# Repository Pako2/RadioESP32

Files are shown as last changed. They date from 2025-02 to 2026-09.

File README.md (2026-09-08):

# RadioESP32
RadioESP32 is a high-performance multimedia platform built on the ESP32 architecture. Originally starting as a dedicated standalone internet radio, the platform has evolved significantly. Starting with version 2.0.0, the project has been completely re-engineered into an advanced multi-boot system that transforms a single hardware device into an Internet Radio player, a local SD card audiobook player, and a high-fidelity Bluetooth loudspeaker – all managed by an independent recovery and deployment application.\
**Note:** Complete project documentation can be found in the [UserGuide_EN.pdf](doc/UserGuide_EN.pdf) file.

### Display and embedded web server preview
For illustration, you can see three photos of the display. You may be surprised to see that some of the text lines are blurred. The explanation is simple. This is scrolling text, because otherwise it wouldn't fit on the display!\
The first picture shows the radio playing, the second shows a file playing from an SD card, and the third shows the clock.
<p float="left">
  Radio player
  SD player 
  Clock
</p>

There's no need to describe the appearance of the web interface. You can learn much more from a few screenshots.
<p float="left">
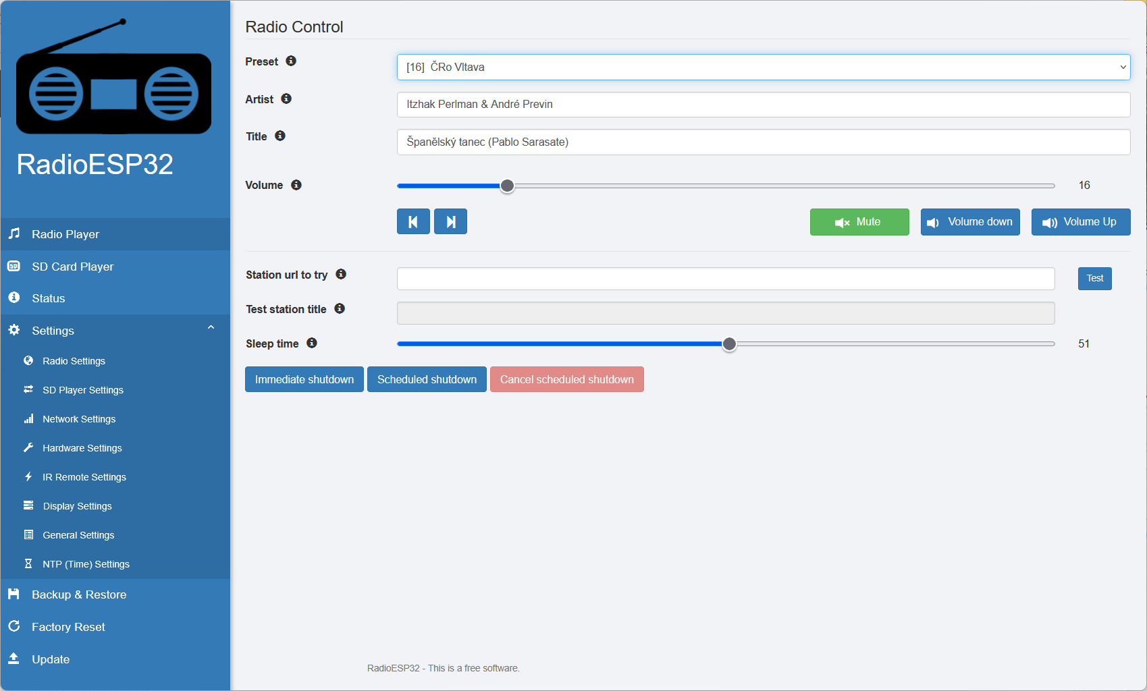
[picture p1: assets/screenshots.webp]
Screenshots
  
</p>

## Project Origin & Acknowledgments
This project would likely never have been created without the popular [ESP32Radio-V2](https://github.com/Edzelf/ESP32Radio-V2) project by [Edzelf](https://github.com/Edzelf). I am deeply grateful to the author for his outstanding work, which served as the original foundation for this software.

While I initially deployed the original project in its unchanged form, several limitations quickly became apparent. My primary motivation for rewriting and expanding the software stemmed from two major issues:

- **Localization:** The original display implementation did not support accented diacritics, which was critical for a proper local user experience.

- **Audiobook Playback:** One of my core requirements was the ability to listen to audiobooks from an SD card. Audiobooks require files to be played in a strict, defined alphabetical order. In the original software, copying files from a PC to an SD card resulted in them being indexed and played in a seemingly random order, making sequential listening highly complicated without constant manual track selection.

Additionally, I preferred a different default behavior. Instead of always resuming the last played station at the previous volume level upon power-up, I prefer the device to initialize to a pre-defined default station and default volume. I also planned to integrate entirely new hardware and software features, such as single-button power toggling and an automated sleep/turn-off timer.

Despite these changes, several core elements from Edzelf's project were retained, which significantly aided my early development. Furthermore, the web interface design, the communication method between the ESP32 and the browser, and the configuration file management system were adopted from the [esp-rfid](https://github.com/esprfid/esp-rfid) project - a highly reliable setup I have successfully utilized across multiple designs.

# Evolution in Version 2.0.0+
During development, I realized that with a purely software-driven approach, the existing hardware design could be utilized as a full-featured Bluetooth loudspeaker. To implement this comfortably, version 2.0.0 underwent a fundamental architectural overhaul.
To streamline production and focus on maximum stability, legacy sub-variants (such as designs without a display or designs storing web server assets directly inside a volatile file system partition) were abandoned. Moving forward, the project is maintained as a single production variant: always equipped with a display and always compiling web server assets directly into the program memory. This specific design is mandatory to support the automated multi-boot Update Manager system.

## Upgrading from Version 1.X.X
If you are upgrading an existing device from a 1.X.X release, your configuration file is fully compatible with the new version. However, due to the fundamental architectural changes mentioned above, a clean installation via cable is required:
- **Backup** your current configuration using the Backup & Restore menu in your existing web interface.
- Perform a **full installation** over a USB cable using the new Flash utility (flash.bat).
- **Restore** your configuration file using the Backup & Restore menu in the new version 2.0.0 interface.

**Note:** 
*Before proceeding with the upgrade, please verify that your hardware meets the new minimum requirements (8MB Flash and PSRAM), as legacy 4MB modules are no longer supported.*

## Legacy Differences: Radio Application vs. Edzelf's ESP32Radio
The following enhancements and modifications apply exclusively to the Internet Radio application (and its web configuration) compared to the original Edzelf implementation:

- **Strict Alphabetical Playback:** Fixed the random indexing issue on SD cards. Files and folders are sorted properly, enabling seamless audiobook listening. However, shuffle mode can be turned on as needed.

- **Diacritics & Extended Character Support:** The display engine was rewritten to support full native character mapping and custom fonts.

- **Predictable Initialization:** The device turns on to a user-defined default station and safe volume level rather than resuming the last state.

- **Single-Button Power Toggle:** Hardware-software integration allows turning the entire device completely on and off using the same single physical button.

- **Integrated Sleep Timer:** Supports a configurable sleep countdown that automatically powers down the hardware.

- **Comfortable Web-Based IR Learning:** Unlike the original project, adding or modifying infrared remote control commands is managed through an incredibly intuitive and automated web interface, allowing the device to capture and assign raw hardware codes on the fly.

# Full-Featured Bluetooth Loudspeaker Application
The Bluetooth Loudspeaker mode (running on OTA\_1) is engineered to deliver a premium commercial-grade user experience, offering deep visual feedback and control options rarely found in DIY audio systems.

## Key features include:
- **Identical Display Dashboard:** The physical display mirrors the rich visual interface of the Radio application, showing a real-time battery status indicator, an active volume bar, and a track progress bar.

- **Dynamic Status Icons:** Features clear visual indicators for Bluetooth connectivity (color-coded blue for active connection, grey for disconnected state) along with dedicated Play/Pause status indicators.

- **Rich Metadata & Auto-Scrolling:** Streams live metadata directly from the connected smartphone. Track titles, artist names, and album details are fully processed and rendered with native diacritic support, automatically triggering a smooth text-scrolling engine if the text length exceeds the screen boundaries.

- **Dual Physical Control Layers:** The loudspeaker can be controlled fully via the mechanical physical rotary encoder or completely hands-free using an Infrared Remote Control (handling Play, Pause, Track Skip, and Volume adjustments).

- **Centralized Configuration:** Because the Bluetooth application completely turns off the Wi-Fi stack to eliminate protocol overhead and interference, it does not host a web server. Instead, all Bluetooth-specific settings (including custom broadcast device naming and the advanced IR remote control command learning) are comfortably configured inside the unified web interface of the Internet Radio application.

# System Architecture & Multi-Boot Partitioning
Due to the strict hardware limitations of the ESP32 chip (specifically the high instability and memory constraints of running Wi-Fi and Bluetooth stacks simultaneously) the system separates core features into completely independent firmware binaries.

The system utilizes a custom partition layout designed for 8MB Flash chips. The minimum required hardware configuration is the ESP32-WROVER-E-N8R4 module. Volatile PSRAM memory is mandatory, as modern versions of the underlying audio libraries will not function without it.

## The memory layout divides the hardware into four distinct primary zones:
| Partition Type | Application Name | Core Functionality | Network State |
| - | - | - | - |
| **Factory** | Update Manager | Recovery, deployment, and binary flashing | Wi-Fi (Station with Internet) |
| **OTA\_0** | Internet Radio | Web-streaming, SD card media player | Wi-Fi (Station / Initial AP Setup) |
| **OTA\_1** | BT Loudspeaker | High-fidelity A2DP audio playback | Completely Disabled (No Wi-Fi) |
| **LittleFS** | Configuration | Shared system settings and profiles | Non-volatile storage |

All three applications share a single, unified configuration file stored in the LittleFS zone. Switching between applications triggers a low-level hardware reset using direct RTC controller registry manipulation, ensuring that the hardware cache and DMA controllers are completely cleared for a pure warm boot.

# Independent Update Manager
Because individual OTA application partitions contain completely different binary structures (Radio vs. Bluetooth), traditional OTA upgrades (where a new version is uploaded to an inactive slot and toggled) are impossible.

The project solves this by deploying a completely independent recovery application in the factory partition. When triggered via the display menu or the radio's web interface, the device reboots into the red-themed Update Manager web server (accessible via the credentials defined in the source code). From this dashboard, users can view live tables comparing current firmware versions against the latest versions available online, perform automated network updates, create full system binary backups, or deploy manual downgrades from local files.
<p float="left">
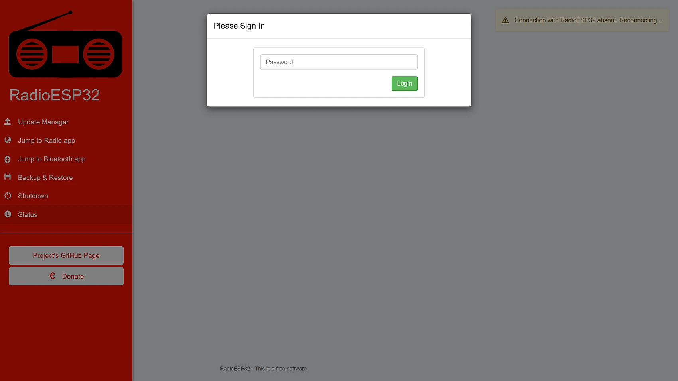
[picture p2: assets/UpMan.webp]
Update Manager
  
</p>

### ⚠️ Important Note regarding Over-the-Air (OTA) Web Upgrades

Due to strict modern browser security standards (CORS policies) implemented by GitHub, web browsers will natively block the JavaScript interface from directly transferring firmware files from GitHub Releases onto your local IP address via the single-click "Update" buttons.

To complete an application upgrade, you have two equally reliable options:

1. **Manual Offline Upload (Recommended & Safest):** 
   Simply click the green **Download** button next to the target application to save the latest `.bin` firmware file directly to your PC. Then, navigate to the **Firmware Upload** panel below, select the correct **Target Application**, click the **Browse...** button to select the downloaded binary from your hard drive, and click **Flash Selected File**.

2. **Direct Web Upgrade (Advanced):**
   If you prefer to upgrade with a single click directly from the web interface using the automated table, you must temporarily enable a CORS-bypass extension in your browser (such as *"Allow CORS: Access-Control-Allow-Origin"* for Chrome/Firefox) before opening the Update Manager dashboard.

The Update Manager features critical system-level fail-safes. If the supply battery drops below a safe operational threshold during an update cycle, an asynchronous JavaScript modal hard-locks the entire web interface, preventing user interactions until safe power parameters are restored, eliminating the risk of accidental firmware bricking.

## Advanced Graphics Engineering
To achieve absolute long-term stability, the graphics pipeline was completely refactored. The Bluetooth application runs an aggressive real-time A2DP data sink. Under standard implementations, multi-core thread collisions frequently occur on the shared SPI display bus when high-priority Bluetooth background tasks on Core 0 interrupt the main application execution loop on Core 1.

The system eliminates these race conditions by removing traditional RTOS mutexes entirely. Instead, all graphic subsystems, status readouts, and display bars (such as the volume bar, battery indicator, progress bars, and scrolling metadata tracks) are completely centralized under a single-task, asynchronous flag-driven pipeline in the display loop. Asynchronous events from Bluetooth callbacks merely flag status variables in RAM, which are safely ingested and drawn by a single dedicated display task.

# Development and Build Flags
The project is developed in VS Code using the PlatformIO IDE paired with the Pioarduino extension. Using environment build flags in `platformio.ini`, the firmware behavior is customized using the following core definitions:

- **DATAWEB=true/false:** Setting this flag to `true` compiles a development variant where web server assets are loaded dynamically from the LittleFS partition, allowing real-time, browser-based source editing via the integrated online [Ace editor](https://ace.c9.io/). Setting this to `false` creates the production variant, compressing and injecting all HTML and JS assets directly into the program memory (PROGMEM) as static variables. This is the mandatory format for deployment binaries.

- **SDCARD:** Compiles full support for the local SD card hardware and alphabetical media player engine.

- **BATTERY:** Enables power monitoring, enabling precise voltage calibration routines and rendering live battery status bars across both the physical display and web dashboards.

- **AUTOSHUTDOWN:** Compiles the control logic for the single-button soft power toggle circuit and the automatic sleep timer.

# Third-Party Libraries & Acknowledgments
This project relies heavily on the open-source community. I would like to express my sincere gratitude to the authors of the following exceptional libraries, whose hard work made this multi-boot platform possible:

- **[ESP32-audioI2S](https://github.com/schreibfaul1/ESP32-audioI2S) by schreibfaul1** – The core engine powering the high-performance internet radio streaming and SD card media playback.

- **[ESP32-A2DP](https://github.com/pschatzmann/ESP32-A2DP) by pschatzmann** – The backbone of the Bluetooth application, providing a reliable and robust real-time A2DP audio sink.

- **[ESPAsyncWebServer](https://github.com/ESP32Async/ESPAsyncWebServer)** – Essential for driving the asynchronous, responsive web interfaces across the platform slots.

- **[ArduinoJson](https://github.com/bblanchon/ArduinoJson) by bblanchon** – Used for fast, memory-efficient parsing of configuration files and the update manager tables.

- **[base64](https://github.com/Densaugeo/base64_arduino) by Densaugeo** – Utilized for secure encoding and handling of system assets and network communication data.

- **[Arduino-IRremote](https://github.com/Arduino-IRremote/Arduino-IRremote)** – Powering the automated infrared remote control receiver and code-learning capabilities.

- **[TFT\_eSPI](https://github.com/Bodmer/TFT_espi) by Bodmer** – The highly optimized graphics driver used to render sprites and smooth scrolling text on the SPI display.

- **[U8g2](https://github.com/olikraus/u8g2) by olikraus** & **[U8g2\_for\_TFT\_eSPI](https://github.com/Bodmer/U8g2_for_TFT_eSPI) by Bodmer** – Providing the comprehensive font support required for native localization, accented diacritics, and system icons.

## PlatformIO Environment & Custom Python Targets
The project utilizes advanced customization features of PlatformIO with the Pioarduino extension to automate the compilation, transformation, and deployment of firmware slots. Since standard environment filters naturally restrict automated serial flashing to the `OTA_0` partition, a dedicated set of specialized automation scripts was engineered to streamline the development workflow:

- **`app_deploy.py` (Binary Archiving):** Executed automatically post-build. It automatically moves and renames compiled images into the structured `/bin/<env>/` directory, preparing them for deployment.

- **`custom_targets.py` (Advanced Workflow Automation):** Exposes core system functions accessible comfortably directly via the *Pioarduino: Project Tasks / \<env\> / Custom* IDE side menu. It processes two critical automated workflows:

  - **Download FS & Create WEBH:** Automates the complete transformation of production web assets. It downloads the live file system image from the hardware using maxgerhardt's downloader utility, extracts the HTML and JS assets from `LittleFS`, and translates them directly into compressed C++ array data variables ready for `PROGMEM` generation.

  - **Upload custom binary:** The primary development flashing mechanism. Instead of pushing blindly to `OTA_0`, this target programmatically parses the local partition configuration table, dynamically locates the precise memory address boundaries for the active target environment, and executes a targeted wired upload directly to the correct slot (`OTA_1` for Bluetooth loudspeaker or `factory` for the Update Manager).

## Production Flash Utilities
For initial provisioning, assembly, and bulk deployment outside the VS Code IDE development sandbox, a dedicated, standalone host script named Flash Utilities is used.
<p float="left">
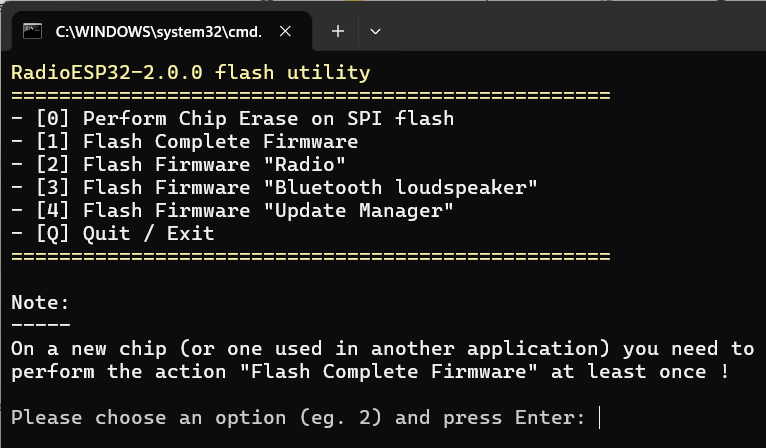
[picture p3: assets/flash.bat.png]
Flash menu
  
</p>
This standalone batch utility operates strictly as a master installation tool tailored for two main deployment scenarios:

1. **Full Environment Initialization:** Performs the first-time wired flashing of a fresh, raw ESP32 chip. It writes the global bootloader configurations, custom multi-boot partition boundaries, the initial `LittleFS` shared configuration image, and all three application binaries concurrently.

2. **Targeted Service Upgrades:** Provides a safe serial bypass tool to manually write or restore a single specific slot over a wired serial connection. This is the mandatory path required for initial installation or forced rewrites of the factory recovery application partition without formatting or impacting user profiles.

On a fresh device provisioning cycle, the system triggers a default fallback standalone Wi-Fi Access Point named **RadioESP32**. Navigating a web browser to `192.168.4.1` loads the initial onboarding setup screen to connect the multi-boot hardware platform to local wireless station configurations.

# Hardware Design & Component Selection
The physical hardware architecture is designed using the free/personal-use tier of Autodesk Eagle, utilizing a dual-stage isolation approach to completely eliminate ground loops, digital switching noise, and interference.

### Wiring diagram
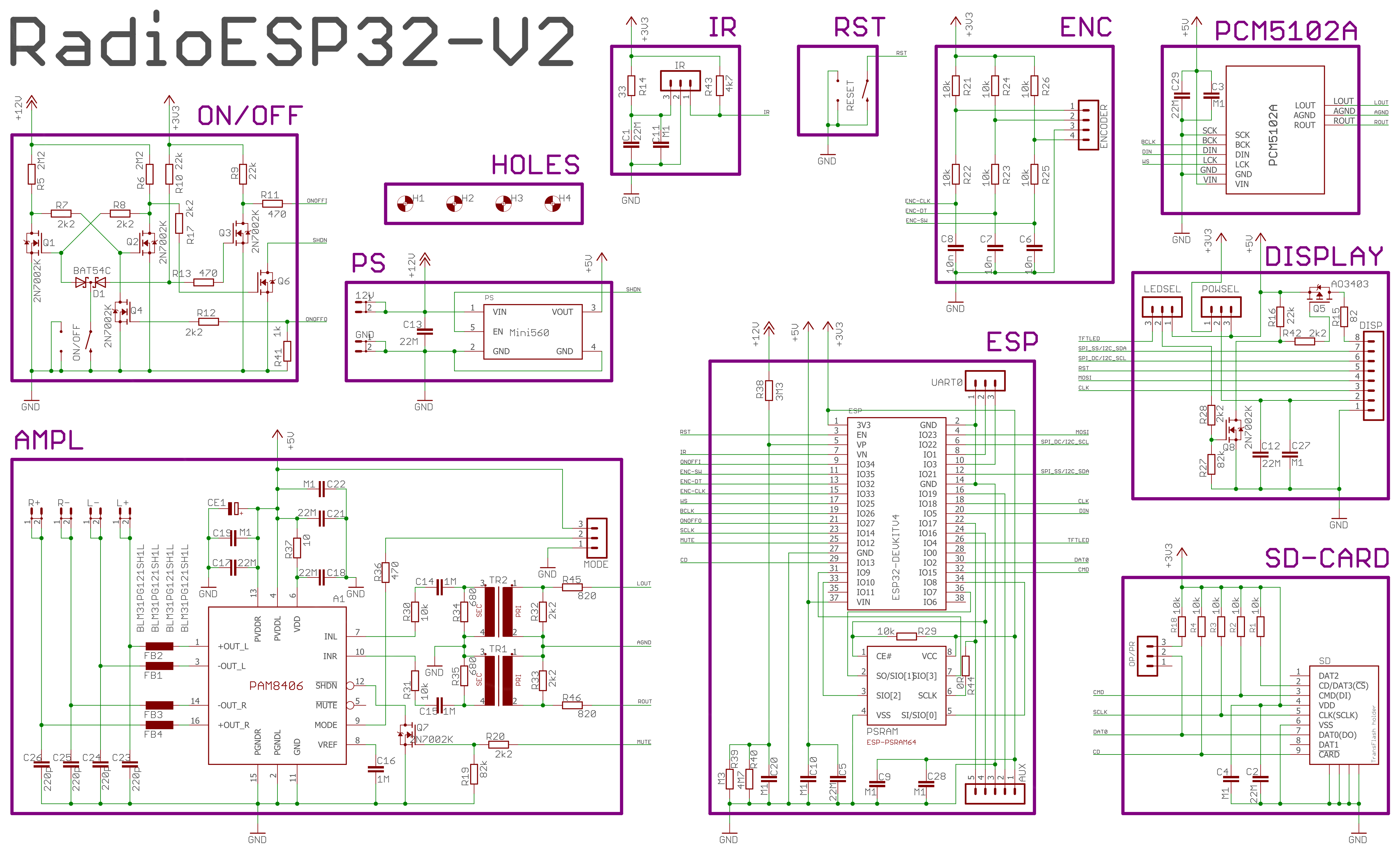
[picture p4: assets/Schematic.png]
Wiring diagram


### Printed circuit board
<p float="left">
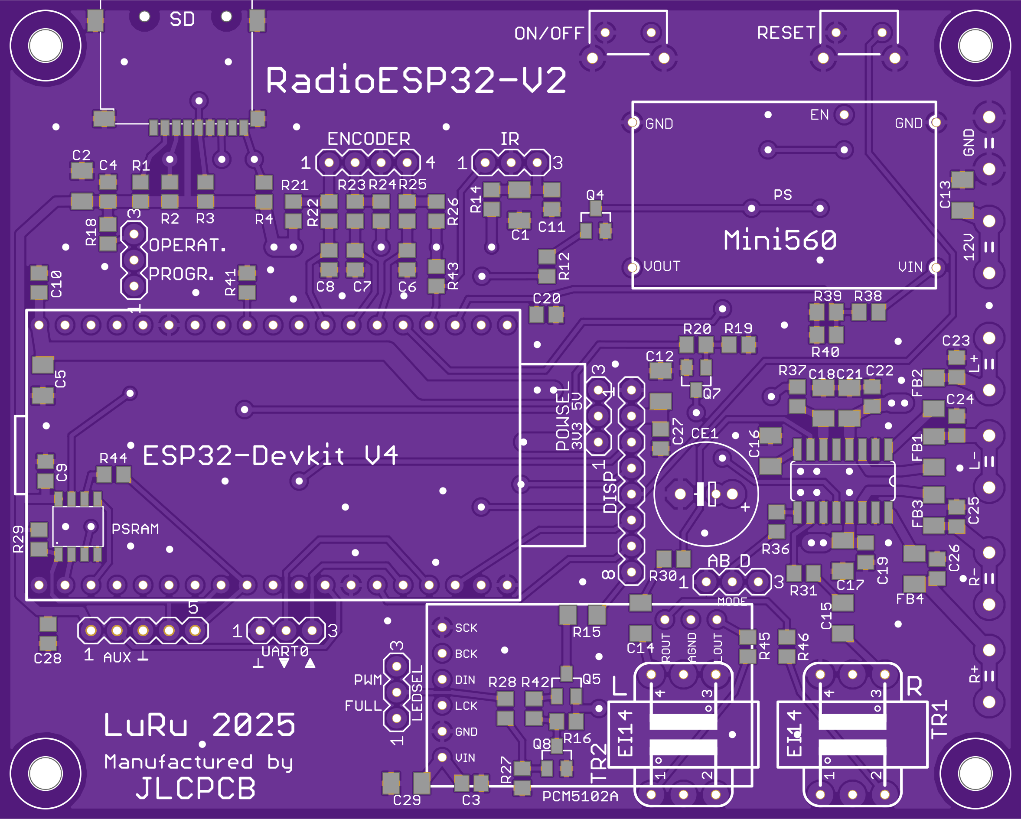
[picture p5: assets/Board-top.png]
PCB top side
  
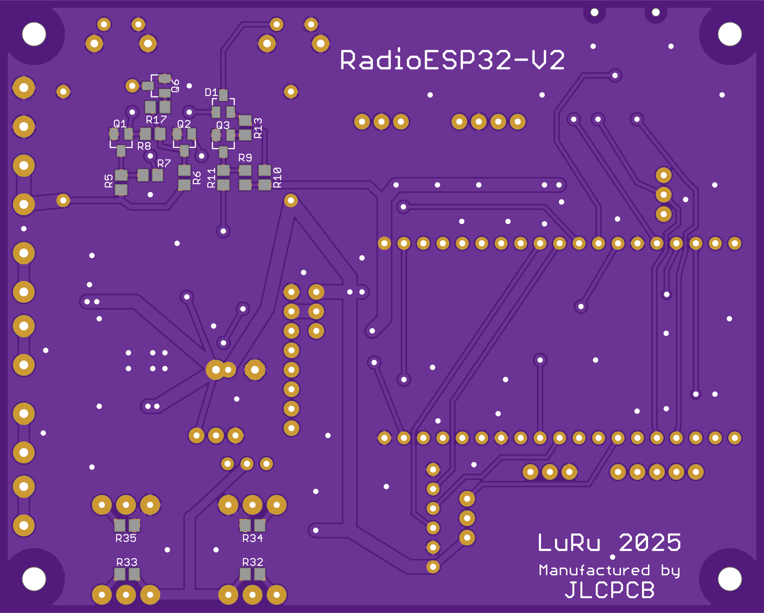
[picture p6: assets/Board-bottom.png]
PCB bottom side
   
</p>

### Choice of components
In the first phase of development, I used the VS1053 module (as a DAC) following Edzelf's example. It worked well, but I found this solution unnecessarily expensive and quite problematic (for example, I once accidentally bought a VS1003 instead and it didn't work well). That's why I completely abandoned this path and switched exclusively to a solution with I2S.
- **Main Processor:** ESP32-WROVER-E module (Silicon Revision 3 or higher, minimum 8MB Flash and 4MB PSRAM).
<p float="left">
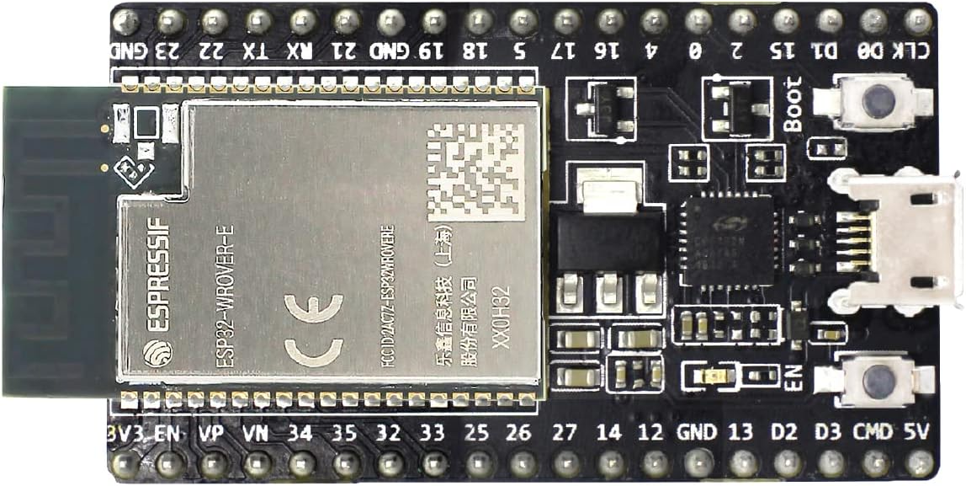
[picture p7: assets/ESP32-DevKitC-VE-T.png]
Development board - top side
  
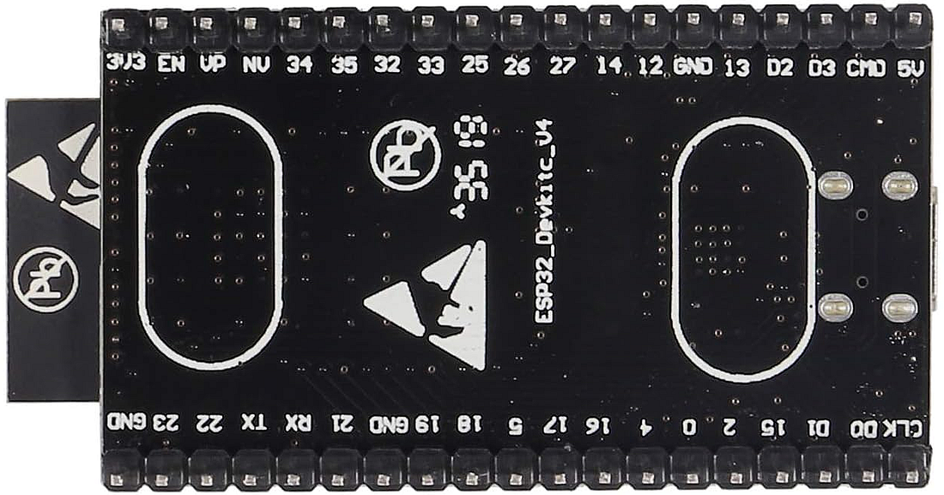
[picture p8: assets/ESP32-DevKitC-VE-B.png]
Development board - bottom side
   
</p>

- **Power Supply:** 12V primary input, optimized to run efficiently from three series-connected 18650 Li-ion cells or a standard wall adapter. A high-efficiency Mini560 step-down module regulates this down to a stable 5V rail. The module's EN (Enable) pin is directly wired into the single-button latching circuit for hard physical power management.
<p float="left">
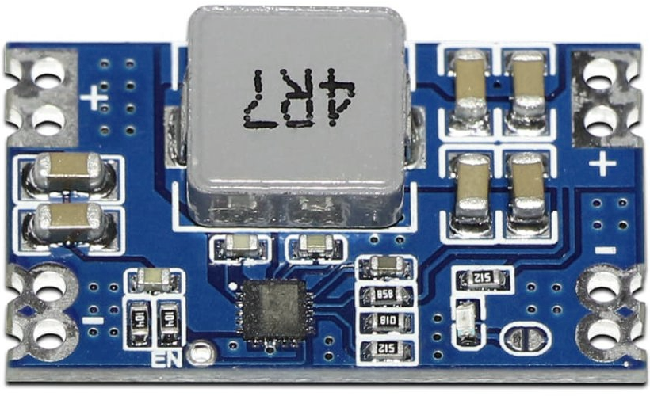
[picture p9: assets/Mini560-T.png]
Step-down converter top side
  
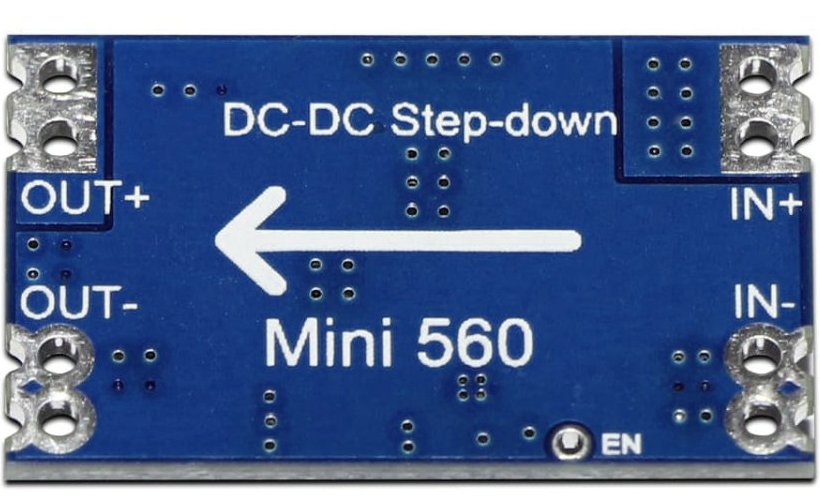
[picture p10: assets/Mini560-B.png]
PStep-down converter bottom side Step-down converter bottom side
   
</p>

- **Audio DAC:** PCM5102A I2S module, selected for its high dynamic range and integrated analog out pin liars, eliminating complex internal chassis cabling.
<p float="left">
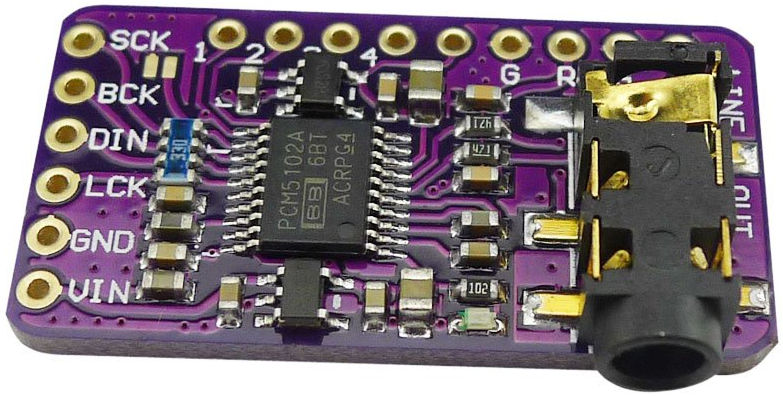
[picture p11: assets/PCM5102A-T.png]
DAC - top side
  
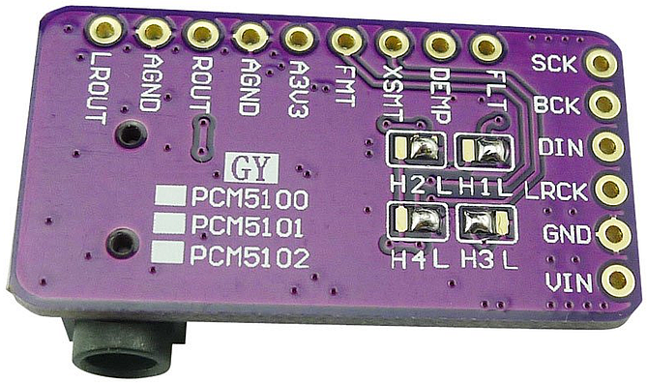
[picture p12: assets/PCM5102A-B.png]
DAC - bottom side
   
</p>

- **Ground Loop Isolation:** Two low-profile 9.1mm audio isolation transformers are placed inline directly between the DAC outputs and the amplifier inputs, successfully blocking digital hum and cross-talk.
<p float="left">
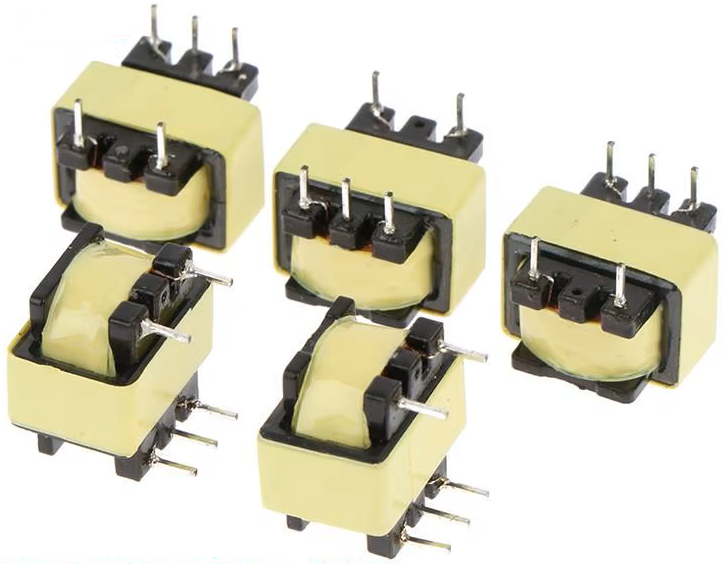
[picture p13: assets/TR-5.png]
Isolation transformers
  
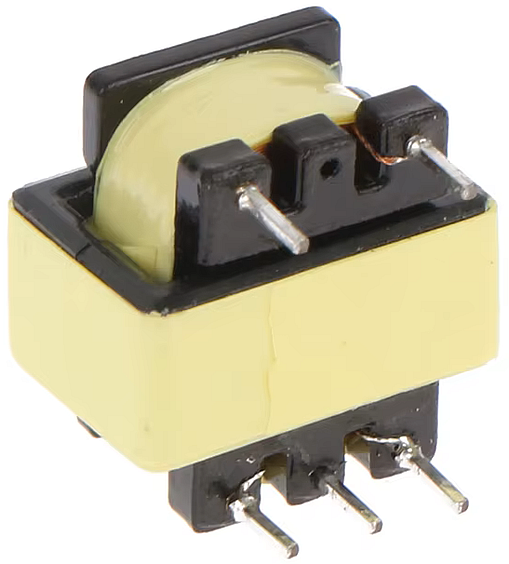
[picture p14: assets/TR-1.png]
Isolation transformer
   
</p>

- **Amplifier Stage:** PAM8406 5V stereo amplifier IC. This specific chip was chosen because it can operate in either Class-D (high efficiency for battery operation) or Class-AB (low RF noise for clean radio reception). The operating mode is manually selected on the PCB via hardware jumpers.
<p align="center" width="100%">
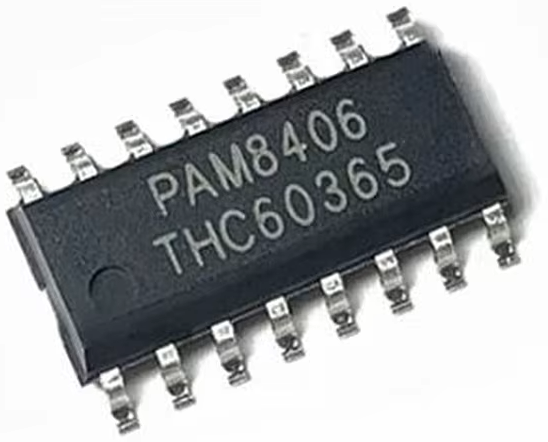
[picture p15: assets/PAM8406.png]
Amplifier amplifier
    
</p>

- **Display Interface:** 1.77-inch SPI TFT panel (160x128 resolution) driven natively by the optimized TFT\_eSPI library.
<p float="left">
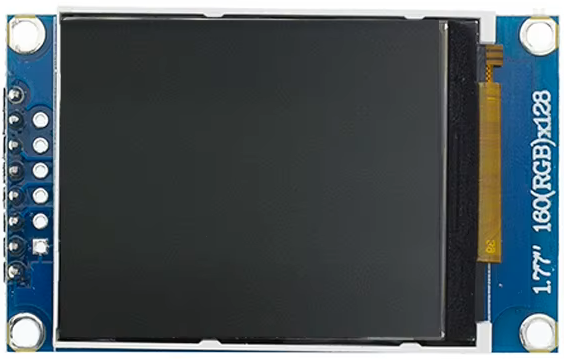
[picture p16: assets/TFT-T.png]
TFT - top side
  
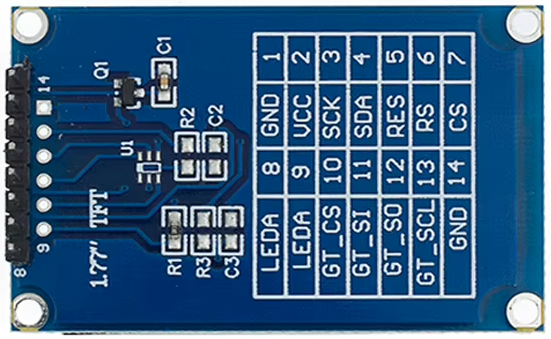
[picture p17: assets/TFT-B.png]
TFT - bottom side
   
</p>

- **User Control:** A robust EC11 mechanical rotary encoder with an integrated push-button handles physical navigation, complemented by a VS1838B infrared receiver supporting automatic remote control code learning.
<p float="left">
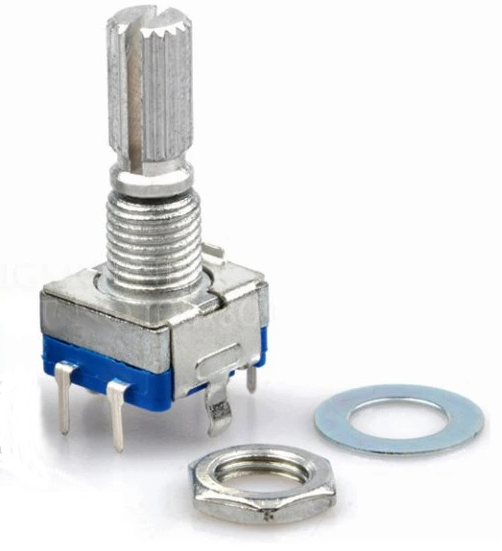
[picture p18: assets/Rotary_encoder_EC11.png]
Rotary encoder
  
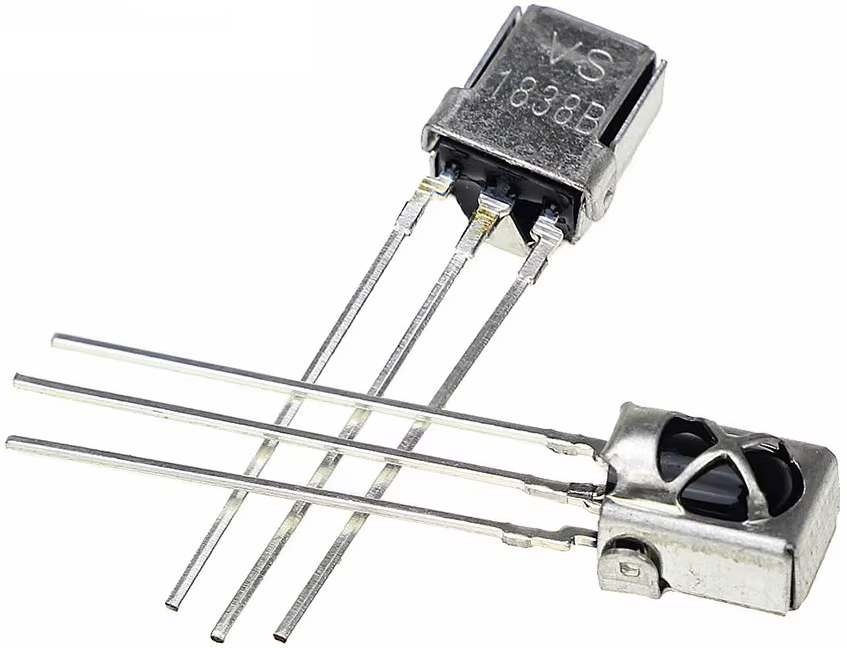
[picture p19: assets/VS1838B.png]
Infrared receiver
   
</p>

- **Chassis Connections:** Traditional screw terminals were replaced with high-reliability 4.8mm male Faston terminals soldered directly to the PCB for all primary power inputs and speaker outputs, ensuring vibrating-proof connections inside the speaker enclosure.
<p float="left">
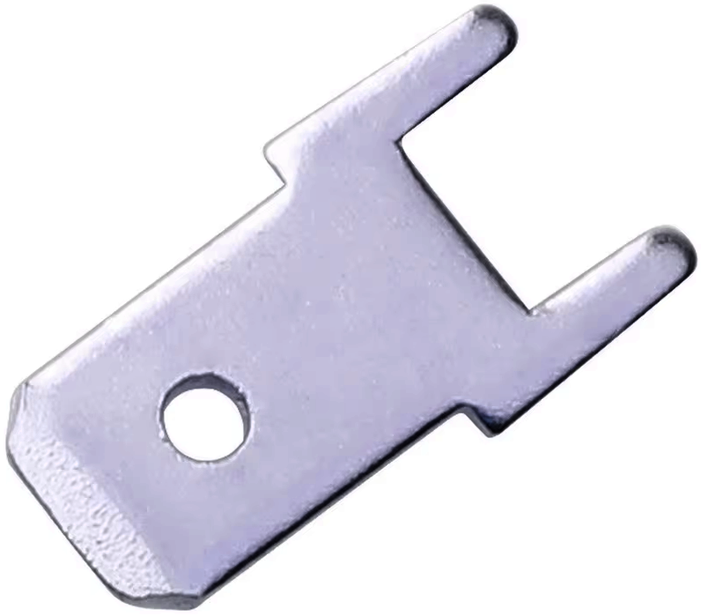
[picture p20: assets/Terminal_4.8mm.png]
Faston connector
   
</p>

## Assembled board
Finally, you can see a few pictures of the printed circuit board completely assembled and including the installed subboards (ESP32 development kit and DAC). I also added one photo of the finished radio (powered by three 18650 Li-ion cells).

PCB 1
PCB 2
PCB 3
PCB 4
PCB 5
PCB 6
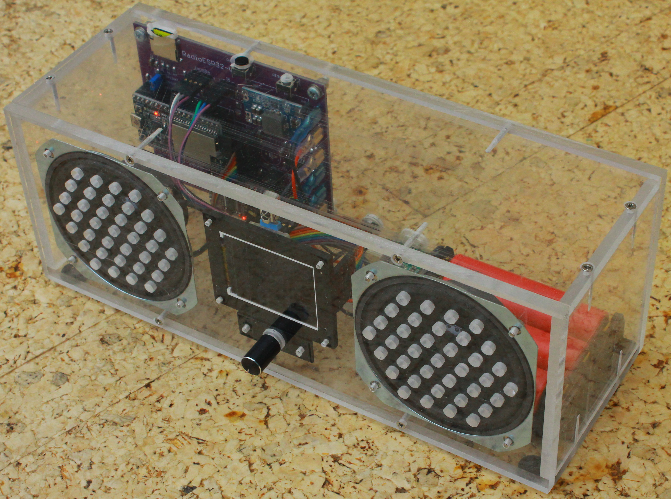
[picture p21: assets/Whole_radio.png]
RADIO


### License
The code parts written by the author of the **RadioESP32** project are licensed under [GPL-3.0](LICENSE), 3rd party libraries that are used by this project are licensed under different license schemes, please check them out as well.

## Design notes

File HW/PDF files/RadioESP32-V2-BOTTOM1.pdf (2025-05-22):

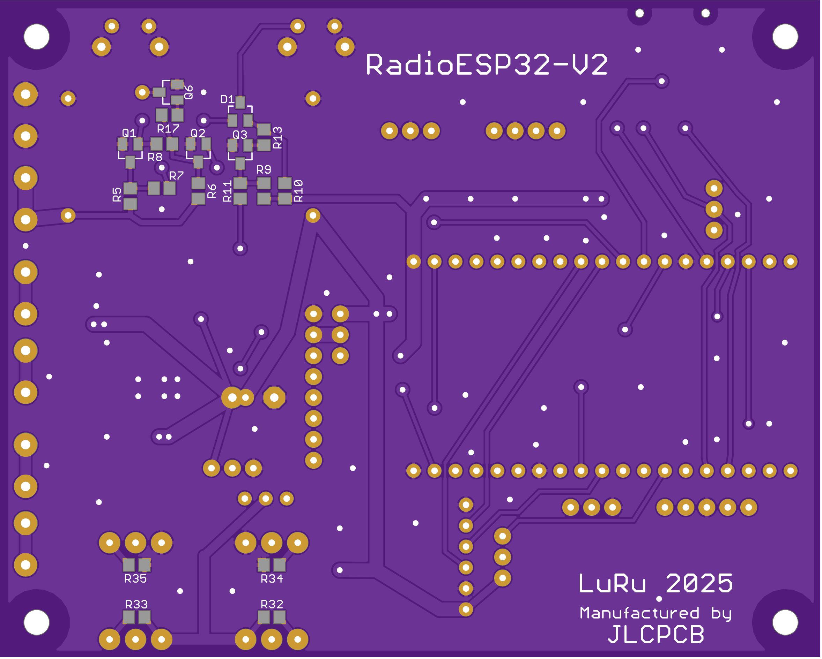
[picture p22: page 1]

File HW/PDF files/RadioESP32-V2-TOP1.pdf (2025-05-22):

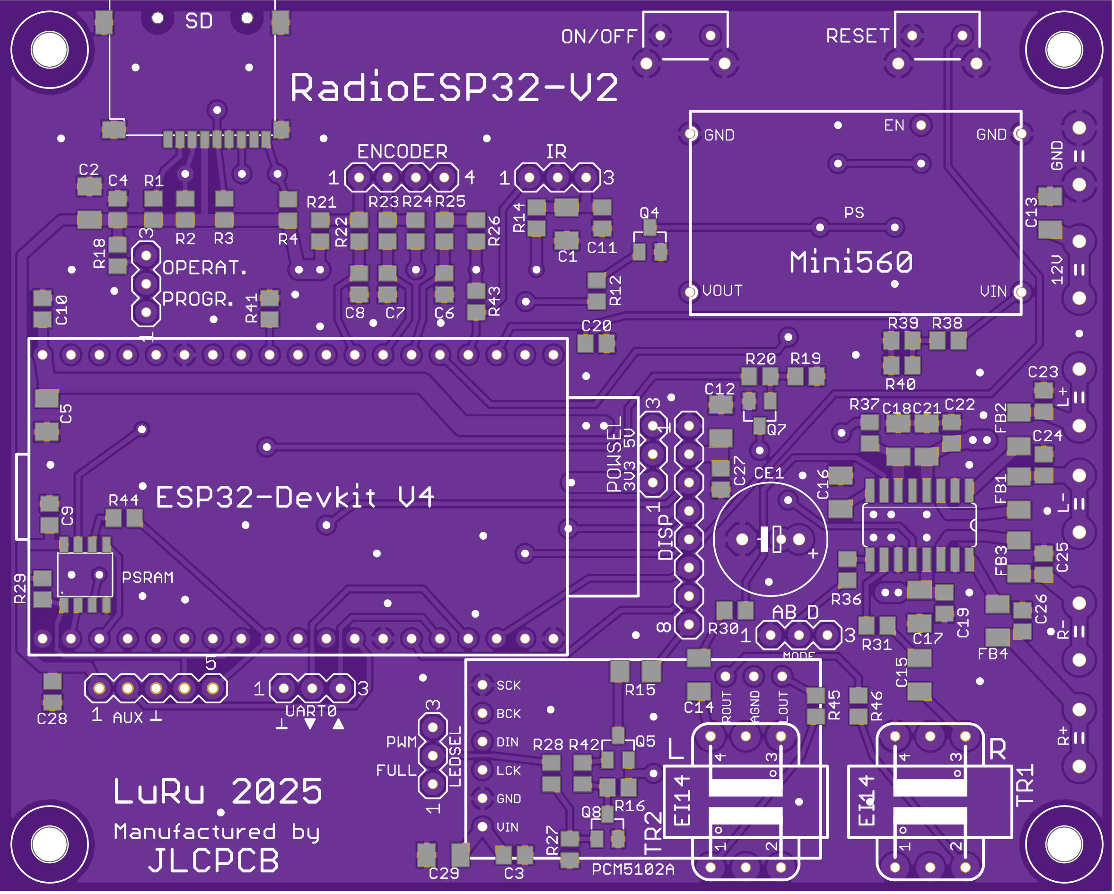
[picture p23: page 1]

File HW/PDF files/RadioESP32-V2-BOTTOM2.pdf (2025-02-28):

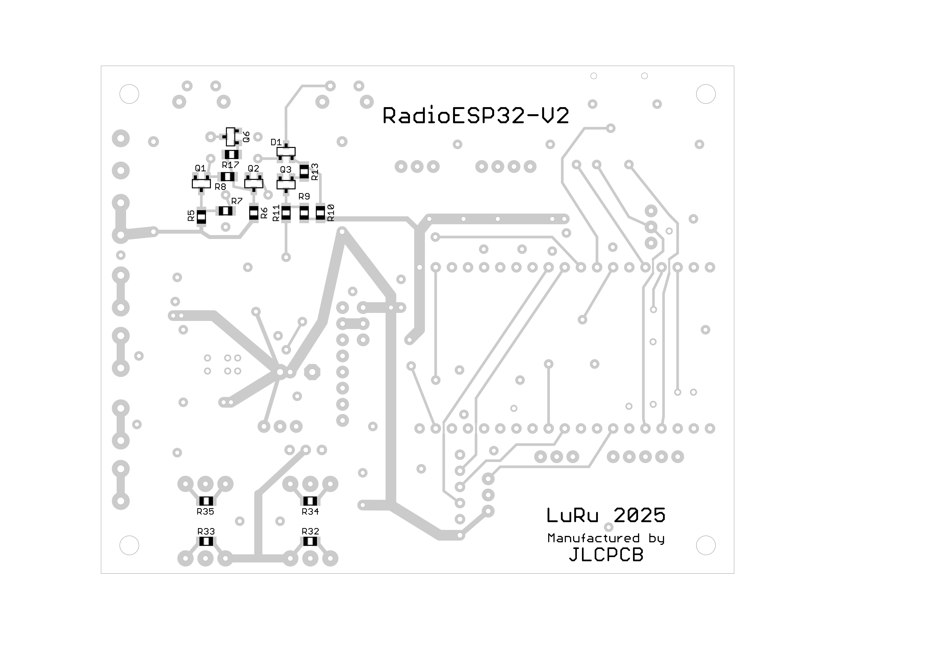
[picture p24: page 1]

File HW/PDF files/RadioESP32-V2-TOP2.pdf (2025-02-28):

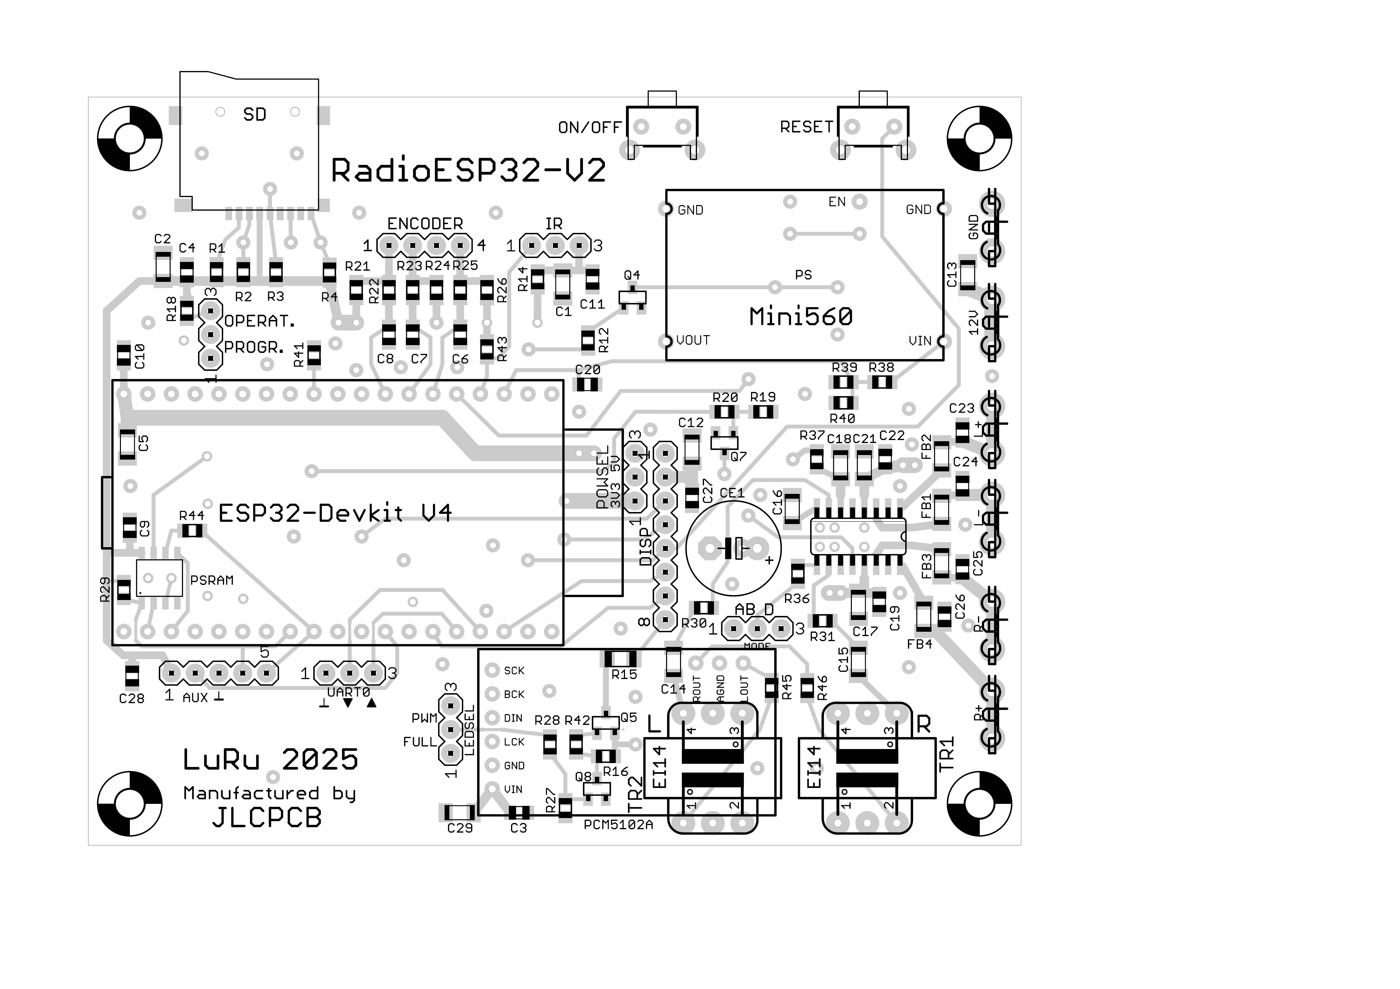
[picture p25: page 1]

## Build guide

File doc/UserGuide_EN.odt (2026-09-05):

RadioESP32

Introduction

Right at the start, it should be mentioned that this project would probably never have been created without the popular "ESP32Radio-V2" project by Edzelf. I am deeply grateful to the author for his work and thank him for his efforts.
Originally, I adopted the original project without any changes, but very soon it ceased to suit my needs. I was particularly bothered by the fact that the display did not show diacritics (accented characters).
The second major issue for me was the behavior of the SD card file player. One of my requirements for the device was to allow listening to audiobooks. In such a case, however, the files must be played in a defined (i.e., alphabetical) order. But this did not work with the original software. After copying files from a HDD to an SD card, the files always arranged themselves in a somewhat random order, making listening to individual chapters in the correct sequence very complicated (the correct chapter had to be selected manually).
Apart from these two issues, there was a whole range of minor details that I envisioned working differently. For example, the feature that ensured that the last listened-to station always played upon power-up (and with the last used volume level). This did not suit me at all; I prefer the device to play a default station at a default volume when turned on. Furthermore, I planned to add some new features that the original design lacked. Specifically, I wanted the radio to be turned on and off by pressing a single (the same) button, and I wanted it to include a sleep function (i.e., automatic shutdown after a set time).
Despite these facts, I adopted several elements from the original "ESP32Radio-V2" project almost without change, which made my work much easier.
The website design, the method of communication between the ESP32 and the computer (via WebSockets), and several other solutions (such as working with the configuration file) are adopted from the esp-rfid project.

Note on Version 2.X.X
I realized that the exact same hardware could function not only as an Internet Radio but also as a convenient Bluetooth Speaker. I finally managed to realize this idea (after many dozens of hours of work), and so from version 2.0.0, the project has been fundamentally redesigned. Because this involved truly massive changes, to simplify things, I dropped the creation of various sub-variants, such as variants without a display or variants with the web server files located in the file system. Now, the release of a new version is limited to a single variant. This variant always includes a display and always stores the web server files in the program memory. Otherwise, it would not even be possible to use the unique solution with the Update Manager (detailed below).

Warning: From version 2.0.0, the minimum required flash memory size is 8MB. The recommended module (minimum configuration) is ESP32-WROVER-E-N8R4.
PSRAM memory is absolutely essential, especially for the Internet Radio application, as newer versions of the ESP32-audioI2S library will not function without it.

Device Architecture
Due to the hardware limitations of the ESP32 chip (problematic simultaneous operation of WiFi and Bluetooth or memory size), I decided on a solution where both applications (Internet Radio and Bluetooth Speaker) are completely separate and reside in their own partitions. As soon as the device receives a command to switch to another application, it automatically performs a reset and boots up as the newly selected application. It is therefore a so-called multi-boot system.
The Bluetooth Speaker application does not use WiFi at all and thus cannot have its own web interface. This is resolved by having both applications share a common configuration file; all configuration (including that pertaining exclusively to the Bluetooth Speaker) is performed within the Internet Radio environment.
As a consequence of having a different application in each "OTA" type partition, it is not possible to use the classic method of installing upgrades (where the new version is saved to the inactive partition and then switched to). Therefore, it was necessary to create a completely new upgrade system. The result is a third, completely independent application called the Update Manager, which is located in the "factory" partition. This application has its own web interface, through which the Internet Radio and Bluetooth Speaker applications can be conveniently upgraded. The Update Manager application itself can only be upgraded "via cable".

The following table clearly shows the layout of the most important flash memory areas:

Flash Memory Area | Application / Data
factory | Update Manager
OTA_0 | Internet Radio
OTA_1 | Bluetooth Speaker
SPIFFS / LittleFS | Configuration Data

Development with VS Code and PlatformIO
I use VS Code/PlatformIO as my development environment. An important feature of the PlatformIO IDE is that, thanks to the platformio.ini file, it is possible to create multiple software variants. This is done using so-called build_flags. For the RadioESP32 project, the critical build_flags are DATAWEB, SDCARD, BATTERY, and AUTOSHUTDOWN.

- Using the build_flag DATAWEB=true compiles the software version that has the web server files stored in the "LittleFS" file system area, whereas setting the parameter to false compiles the software version in which the web server files are stored in the program memory (using the PROGMEM attribute) in the form of variables. I call the first version data for short, and the second webh. The data variant is intended exclusively for the development phase, while the webh variant is intended for production.
- Using the build_flag SDCARD enables support for the SD card file player function. Without using this build_flag, the Internet Radio application can only play radio stations.
- Using the build_flag BATTERY enables support for the supply voltage measurement function. This is naturally suitable for battery-powered setups. The display will then show the battery charge level.
- Using the build_flag AUTOSHUTDOWN enables support for the feature allowing the device to be turned on and off with a single button, as well as the sleep function (adjustable automatic shutdown time). This requires the hardware to be equipped with the necessary circuit.

Three envs are defined in the platformio.ini file, one for each of the three applications. The default env can be chosen by commenting/uncommenting in the [platformio] section. During development, however, switching between applications this way is impractical. It is much simpler to use the Pioarduino: Project Tasks menu on the left side of the screen. However, this requires the Pioarduino extension to be installed in VS Code. The Build action can be found under Pioarduino: Project Tasks/<application>/General. The Upload action is also located there, but it cannot be used (with the exception of the Internet Radio application). PlatformIO consistently performs uploads to the OTA_0 partition. I bypassed this by creating a script to upload to the correct partition. The script reads the correct partition address directly from the table and then performs the upload (but only for the application, it does not upload anything else). The script can be executed by selecting Pioarduino: Project Tasks/<application>/Custom/Upload custom binary. This procedure is the only option available for the Bluetooth Speaker and Update Manager applications. Conversely, the Internet Radio application can also be uploaded in the standard way. Doing this at least once is necessary to ensure that the bootloader and partition table are uploaded as well.

Using the DATAWEB build_flag, I proceed with software development as follows:

1. Development takes place exclusively in the data software variant (in the platformio.ini file, the build_flag DATAWEB is set to true). After modifying the source files, compilation is performed in the usual way, and the device is upgraded via the USB (serial) port.
2. If it is necessary to modify the *.html or *.js web server files to fix an error or add a feature, you must open the page http://<device_IP_address>/edit. For this to work, the PC must be connected to the internet, as the online "ace" library (Ajax.org Cloud9 Editor) is used for editing. See https://ace.c9.io/ for more details.
3. Once the desired functionality is achieved using steps 1 and 2, the webh software variant must be created. This is done by running the user script Download FS & Create WEBH, which is also available in the Pioarduino: Project Tasks/<application>/Custom menu. This transforms the web server files (from the LittleFS file system) into webh files. The "pio-esp32-esp8266-filesystem-downloader" utility by maxgerhardt is used to download and extract the file system image.
4. The entire process ends by switching to the webh variant. In the platformio.ini file, the build_flag DATAWEB must be set to false and compilation performed. The resulting image <application>_vX.X.X.bin (created during the compilation process) can be found in the /bin/<application> directory. The version designation "X.X.X" is also set before compilation in the platformio.ini file as a build_flag.

Firmware Installation
The firmware must always be installed onto a new ESP32 (or one previously used in another application) via a cable. There are two options: either directly from the VS Code environment or using the Flash utility.

Installation via VS Code
This method is chosen by experienced users who compile the firmware themselves and can therefore customize it to their needs (either via build_flags or by modifying the code).
Due to the multi-boot architecture, the installation procedure is specific. To avoid having to switch the default env before compiling and uploading individual applications by editing platformio.ini (commenting out lines in the [platformio] section), you can advantageously use the Pioarduino: Project Tasks sidebar menu. For uploading the menu_app and btls_app applications, this is the only option!

Procedure:

1. Compile the radio_app application using Project Tasks/radio_app/General/Build.
2. Upload the radio_app application image using Project Tasks/radio_app/General/Upload. This will upload not only the application binary but also the partitions.bin and bootloader.bin files.
3. Compile the btls_app application using Project Tasks/btls_app/General/Build.
4. Upload the btls_app application image using Project Tasks/btls_app/Custom/Upload custom binary.
5. Compile the menu_app application using Project Tasks/menu_app/General/Build.
6. Upload the menu_app application image using Project Tasks/menu_app/Custom/Upload custom binary.

If everything went smoothly, the firmware is installed. You can proceed to the First Boot chapter.

Installation via Flash utility

For less experienced users (who are content with precompiled firmware), I have prepared the Flash utility script.

Warning: Before running the installation, make sure that the selected COM port is not being used by another program (e.g., the serial monitor in VS Code), otherwise esptool.exe will fail to connect to the chip.

Installation procedure (assuming the ESP32 is connected to the computer via a USB cable):

1. Download the installation package: https://github.com/Pako2/RadioESP32/releases/latest/download/RadioESP32_binaries.zip
2. Extract the downloaded package into a suitable folder - let's call it RadioESP32, for example.
3. Open Windows Explorer and navigate to the chosen folder (RadioESP32).
4. Run (e.g., by double-clicking) the flash.bat file. This automatically launches a more modern PowerShell script, flash_utility.ps1 (Windows security will safely bypass the script restriction), and the menu shown below will appear.
5. Recommended (optional) step – option [0] – Perform Chip Erase on SPI flash.
6. Mandatory step – option [1] – Flash Complete Firmware (if step 5 was also performed, you must run flash.bat again).


If everything went smoothly, the firmware is installed. After successful flashing, I recommend disconnecting and reconnecting the USB cable (or pressing the EN/RST button on the module). Sometimes, a physical reset is required for the ESP32 after an upload to correctly initialize the partition table and LittleFS.

Notes:
Options [2] to [4] are not intended for the initial installation phase. They can subsequently be used to perform upgrades of individual applications (if for some reason the procedure via the Update Manager is not preferred).
Option [Q] serves to safely exit the utility if the user changes their mind about flashing.

First Boot
When the device is booted for the first time, it runs with default settings and in AP mode. On a PC, connect to the "RadioESP32" network and navigate to the address 192.168.4.1 in a browser. A web page should appear, through which the device configuration must be carried out. The description of the web interface is provided in the Main Menu chapter.

Upgrade
The Internet Radio and Bluetooth Speaker applications can be upgraded very easily via the web interface of the Update Manager application.

Procedure:
a) You can switch to the Update Manager application from the Internet Radio and Bluetooth Speaker applications using the display menu, which can be invoked by long-pressing the rotary encoder knob. The second option is to press the software button Jump to Update Manager, located on the "Check for updates" page. This, of course, applies only to the Internet Radio.

b) After successfully switching applications, the red Update Manager interface will appear instead of the blue Internet Radio web server interface. To enter it, you must enter the password "admin" (as defined in the source text of the Update Manager application).

c) In the menu (on the left side of the screen), select the item Update Manager.

d) A table will appear, displaying both the current versions of the applications and the versions available on the internet.

e) If a newer version exists compared to the current one, you can press the software Update button and then follow the instructions on the screen. The result should be an upgraded application.

Additionally, on the same page, there are buttons that can be used to create backups of the current applications (.bin files). Furthermore, there is also the option to upload (and thus perform a potential downgrade to) any other .bin file available on the computer's disk.

Upgrade from Version 1.X.X to Version 2.X.X

Since the architecture of both versions is completely different, a full installation is required.

Recommended procedure:

- Backup your configuration (via the Backup & Restore menu).
- Perform the upgrade - for example, by following the Installation via Flash utility chapter.
- Restore your configuration (via the Backup & Restore menu).

Main Menu
The main menu is always on the left side of the screen. Description of the main menu items:

Radio Player
Clicking this item opens a page from which the radio can be comfortably controlled.

SD Card Player
This item is only displayed if the software was compiled with the SDCARD option enabled. Clicking this item opens a page from which the functions of the SD card file player can be comfortably controlled.

Status
Clicking this item opens a page showing basic data about the device.

Settings
If you need to adjust the device settings (for example, during the first boot), select the Settings item. Clicking it expands the menu to show nine sub-menus:

- Radio Settings: This page is primarily used to create the list of radio stations. Furthermore, you can set the default station here (which is automatically selected when the device is turned on), the default volume, and simple equalizer values.
- SD Card Settings: This item is only displayed if the software was compiled with the SDCARD option enabled. Only one parameter can be set on this page, which is "Seek step". This is the jump length (forward and backward) in seconds. The default volume and equalizer settings configured on the Radio Settings page also apply to the SD card file player.
- Bluetooth Settings: Some properties of the Bluetooth Speaker can be configured on this page (for example, the name by which the Bluetooth Speaker presents itself).
- Network Settings: The network (or multiple networks) to which the device should connect must be configured on this page. Press Edit Networks and then New Network. In the dialog box that appears, set the required values. The Scan button can be used to search for available networks. After configuration, press Save Changes. Below the network table, it is also possible to change the SSID, IP address, and mask (all in AP mode). The changes must be confirmed by pressing the Save button and subsequently the yellow button containing the text You have uncommited changes, please click here to commit and reboot …. However, it is advisable to use this yellow button only after reviewing all other settings, as the device will restart after its use.
- Hardware Settings: On this page, it is possible to configure some of the GPIO pins used (some are set before compilation in platformio.ini) and several other parameters. The configured values must again be confirmed by pressing the Save button.

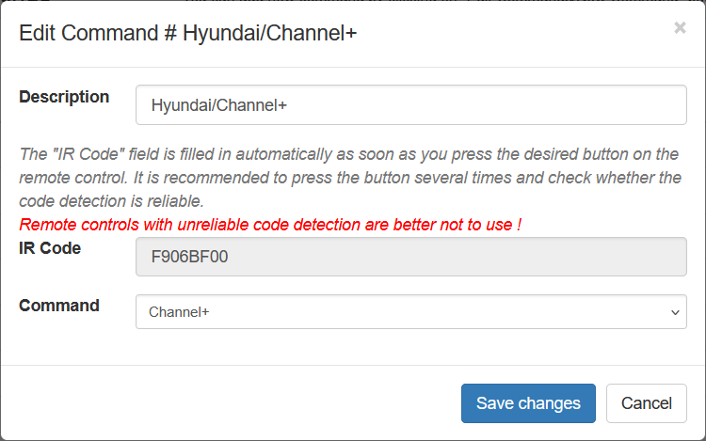
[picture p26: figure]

- IR Remote Settings: Remote control commands are configured on this page. Adding a new command is very simple and intuitive. Configured commands must again be confirmed by pressing the Save button.
- Display Settings: This page allows you to set, in particular, the display backlight levels and the idle clock display settings. The user can also name the days of the week in their own language (by default, the names are in English). As always, the Save button must be pressed after all changes.
- General Settings: It is possible to set the "Machine Name" (Host Name) on this page, and the battery charge level display is also calibrated here. It is confirmed again by pressing the Save button.
- NTP (Time) Settings: The NTP server, synchronization interval (in minutes), and time zone can be configured on this page. Changes are confirmed again by pressing the Save button. Sometimes it may happen that when the device is turned on (or restarted), none of the known WiFi networks are available. In such a case, it is obviously not possible to synchronize the time with the NTP server. In this extreme situation, the Sync Browser Time to Device button will help.

Backup & Restore
In the main menu, we further find the item "Backup & Restore". The meaning is obvious from the name. It is possible to save a file with a backup of the settings to the PC and easily return to the same settings if necessary. Another function is located under the specified item – rebooting the device.

Factory reset
The function of the same name is hidden under this item of the main menu. After its activation, the configuration file is deleted, and after a reboot, the device is in the same state as during the first boot.

Check for updates
If we select this item, a table with the current and available versions of individual applications will appear. It is possible to press the Jump to Update Manager button and switch to the respective application. The subsequent procedure was described in the Upgrade chapter.

Controlling the Device via the Rotary Encoder

Internet Radio Application

- In the basic mode, turning the knob controls the volume, and pressing it toggles Mute on/off.
- Double-pressing the knob switches the device to the radio station selection mode. The preset list is scrolled by turning the knob. The selected station must be confirmed by pressing the knob.
- Triple-pressing the knob switches the device to the SD card file selection mode. Turning the knob scrolls through the track list. The selected file must be confirmed by pressing the knob.
- Long-pressing the knob (about 4 seconds) invokes the application switching menu. Additionally, this menu includes an item that allows turning the device off.

Bluetooth Speaker Application

- In the basic mode, turning the knob controls the volume. The function assigned to pressing the knob can be selected in the Bluetooth Speaker properties settings (via the radio's web interface). By default, pressing the button toggles between Pause and Play.
  The second option (which must be selected in the configuration) is toggling Mute.
- Double-pressing the button switches the device to the track "skipping" mode (forward or backward). In the default state, pressing the knob controls Mute, while the second option (which must be selected in the configuration) is controlling Pause/Play.
- Long-pressing the knob (about 4 seconds) invokes the application switching menu. Additionally, this menu includes an item that allows turning the device off.

Update Manager Application

In the Update Manager application, the rotary encoder only controls the menu for application selection (or turning off). It has no other function.

Controlling the Device via Infrared Remote Control

In the Main menu/Settings/IR Remote Settings chapter, it is described how the device can be taught remote control commands. Commands are shared between the Internet Radio application (including the SD card player) and the Bluetooth Speaker application. The Update Manager application cannot be controlled via IR. Control does not differ from regular multimedia devices and does not need to be described in further detail.

Note:
When entering a preset by number, it is not necessary to confirm the number with the OK command – just wait a brief moment. In contrast, when entering a sleep time, the entered time must be confirmed with the OK command.

Device Hardware Design

The construction is sufficiently described in the README.md file within the project repository. It can be viewed at: https://github.com/Pako2/RadioESP32/blob/main/README.md.

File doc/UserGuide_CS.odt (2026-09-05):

# RadioESP32

Úvod

Hned na úvod se sluší uvést, že tento projekt by asi nikdy nevznikl bez populárního projektu "ESP32Radio-V2" od Edzelf. Autorovi jsem za něj velice vděčný a děkuji mu za jeho práci. Původně jsem samozřejmě převzal originální projekt v nezměněné podobě, ale velice brzy mi to přestalo vyhovovat. Zejména mi vadilo, že displej nezobrazoval znaky s diakritikou.

Druhým největším problémem pro mne bylo fungování přehrávače souborů z SD karty. Jedním z mých požadavků na přístroj bylo, aby umožňoval poslech audioknih. V takovém případě je ale třeba, aby soubory byly přehrávány v definovaném (tedy abecedním) pořadí. Ale to s originálním SW nefungovalo. Po překopírování souborů z HDD na SD kartu se totiž soubory vždy seřadily v jakémsi náhodném pořadí a poslouchat jednotlivé díly ve správném pořadí tak bylo velmi komplikované (správný díl bylo nutné volit ručně).

Kromě uvedených dvou problémů tu pak byla ještě celá řada různých maličkostí, jejichž fungování jsem si představoval jinak. Jako příklad mohu uvést funkci, která zajišťovala, že po zapnutí se vždy přehrávala naposledy poslouchaná stanice (a navíc s naposledy použitou úrovní hlasitosti). To mně ale vůbec nevyhovovalo, já preferuji aby se po zapnutí přístroje přehrávala nějaká výchozí stanice (a výchozí hlasitostí). Dále jsem plánoval přidat nějaké nové funkce, které originální konstrukce neměla. Zejména jsem chtěl, aby rádio bylo možné zapnout a vypnout stiskem jednoho (stejného) tlačítka a aby rádio mělo funkci usínání (tedy automatického vypnutí po nastaveném čase).

I přes uvedené skutečnosti jsem z originálního projektu "ESP32Radio-V2" převzal několik věcí téměř beze změny a moje práce tak byla usnadněna.

Design webových stránek, způsob komunikace mezi ESP32 a počítačem (prostřednictvím websocketu) a několika dalších řešení (například práce s konfiguračním souborem) jsou převzaty z projektu esp-rfid.

Poznámka k verzi 2.X.X
Uvědomil jsem si, že úplně stejný hardware může fungovat nejen jako Internetové rádio, ale také jako komfortní BT reproduktor. Tuto myšlenku se mi nakonec (po mnoha desítkách hodin práce) podařilo realizovat a tak od verze 2.0.0 je projekt zásadně přepracován. Protože to znamenalo skutečně velké změny, tak pro zjednodušení jsem upustil od vytváření různých subvariant, jako byly varianty bez displeje anebo varianty s umístěním souborů webového serveru v souborovém systému. Nyní se tedy vydání nové verze omezuje na jedinou variantu. Ta je vždy s displejem a vždy s uložením souborů webového serveru v programové paměti. Jinak by totiž ani nebylo možné použít unikátní řešení s Update Managerem (podrobněji v dalším textu).

Upozornění: Od verze 2.0.0 je minimální potřebná velikost flash paměti 8MB. Doporučený modul (minimální konfigurace) je ESP32-WROVER-E-N8R4. Paměť PSRAM je nezbytná zejména pro aplikaci Internetové rádio, protože novější verze knihovny ESP32-audioI2S bez ní nefungují.

Architektura zařízení

Vzhledem k HW omezením čipu ESP32 (problematický současný běh WiFi a bluetooth nebo velikost paměti) jsem se rozhodl pro řešení, při kterém obě aplikace (Internetové rádio a BT reproduktor) jsou zcela samostatné a jsou umístěny každá ve svojí partition. Jakmile zařízení obdrží povel k přepnutí do jiné aplikace, automaticky provede reset a startuje už jako nově zvolená aplikace. Jedná se tedy o tzv. multi-boot.
Aplikace BT reproduktor vůbec nepoužívá WiFi a nemůže tak mít vlastní webové rozhraní. To je vyřešeno tak, že obě aplikace sdílí společný konfigurační soubor a veškerá konfigurace (tedy i ta, týkající se výhradně BT reproduktoru) se provádí v prostředí Internetového rádia.

Následkem toho, že v každé partition typu „OTA“ je jiná aplikace, není možné používat klasický způsob instalace upgradů (kdy nová verze se uloží do neaktivní partition a potom se na ni přepne). Proto bylo nutné vytvořit zcela nový systém provádění upgradů. Výsledkem je třetí zcela nezávislá aplikace Update Manager, která je umístěna v partition typu „factory“. Tato aplikace má svoje webové rozhraní, pomocí něhož lze komfortním způsobem upgradovat aplikace Internetové rádio a BT reproduktor. Samotná aplikace Update Manager lze upgradovat pouze „přes kabel“.

Následující tabulka přehledně zobrazuje schéma využití nejdůležitějších oblastí flash paměti:

Oblast | Aplikace / Data
factory | Update manager
OTA_0 | Internetové rádio
OTA_1 | BT reproduktor
SPIFFS / LittleFS | Konfigurační data

Vývoj s VS Code a PlatformIO

Jako vývojové prostředí používám VS Code/PlatformIO. Důležitou vlastností IDE PlatformIO je, že díky souboru platformio.ini je možné vytvořit několik variant software. Provádí se to pomocí takzvaných build_flags. Pro projekt RadioESP32 jsou důležité zejména build_flags DATAWEB, SDCARD, BATTERY a AUTOSHUTDOWN.

● S použitím build_flagu DATAWEB=true se zkompiluje SW ve verzi, která má soubory webového serveru uložené v oblasti souborového systému „LittleFS“, zatímco s parametru false je SW zkompilován ve verzi, ve které soubory webového serveru jsou uložené v programové paměti (pomocí atributu PROGMEM) ve formě proměnných. První verzi říkám zkráceně data, druhé webh. Varianta data je určena výhradně pro fázi vývoje, zatímco varianta webh je určena jako produkční.

● Použitím build_flagu SDCARD se zapíná podpora funkce přehrávače souborů z SD karty. Bez použití uvedeného build_flagu je aplikace Internetové rádio schopna přehrávat pouze rozhlasové stanice.

● Použitím build_flagu BATTERY se zapíná podpora funkce měření napájecího napětí. Je to samozřejmě vhodné v případě napájení z baterií. Displej potom zobrazuje úroveň nabití.

● Použitím build_flagu AUTOSHUTDOWN se zapíná podpora funkce, umožňující zapínání a vypínání přístroje jedním tlačítkem a také funkce sleep (nastavitelná doba automatického vypnutí). Podmínkou je samozřejmě vybavení HW potřebným obvodem.

V souboru platformio.ini jsou definovány tři envs, každý pro jednu ze tří aplikací. Výhozí env se může volit zakomentováním/odkomentováním v části [platformio]. Při vývoji je ale přepínání mezi aplikacemi tímto způsobem nepraktické. Daleko jednodušší je využívat nabídku Pioarduino: Project Tasks v levé části obrazovky. Podmínkou je ale instalace doplňku Pioarduino ve VS Code. Akce Build se nachází v nabídce Pioarduino: Project Tasks/<aplikace>/General. Akce Upload se tam nachází také, ale není ji možné využívat (s výjimkou aplikace Internetové rádio). PlatformIO totiž zcela důsledně provádí upload vždy do partition OTA_0. To jsem obešel tak, že pro upload do správné partition jsem vytvořil skript. Skript si přečte adresu správné partition přímo z tabulky a pak provede upload (ale pouze aplikace, neuploaduje nic jiného). Skript lze spustit pomocí výběru položky Pioarduino: Project Tasks/<aplikace>/Custom/Upload custom binary. Tento postup je v případě aplikací BT reproduktor a Update Manager jediný možný. Naopak aplikaci Internetové rádio lze uploadovat i běžným způsobem. A alespoň jednou je to i nutné provést, aby se uploadovaly také bootloader a tabulka oblastí.

###### Za použití build-flagu DATAWEB postupuji při vývoji SW takto:

1) Vývoj probíhá výhradně ve variantě software data (v souboru platformio.ini je build_flag DATAWEB nastaven na hodnotu true). Po úpravě zdrojových souborů se obvyklým způsobem provede kompilace a přístroj se upgraduje přes USB (sériový) port.

2) Pokud je pro opravu nebo přidání nějaké funkce nutné upravit i soubory *.html nebo *.js webového serveru, je třeba otevřít stránku http://<IP adresa přístroje>/edit. Aby to fungovalo, PC musí být připojen na internet. K editování je totiž využívána online knihovna „ace“ (Ajax.org Cloud9 Editor). Více viz https://ace.c9.io/.

3) Jakmile se pomocí kroků 1 a 2 dosáhne požadované funkcionality, je třeba vytvořit webh variantu software. To se provede spuštěním uživatelského skriptu Download FS & Create WEBH, který je také dostupný v nabídce Pioarduino: Project Tasks/<aplikace>/Custom. Tím dojde k transformaci souborů webového serveru (ze souborového systému LittleFS) do souborů webh. Ke stažení obrazu souborového systému a jeho extrakci je použita utilita „pio-esp32-esp8266-filesystem-downloader“ od maxgerhardt.

4) Celý proces končí přepnutím na variantu webh. V souboru platformio.ini je třeba build_flag DATAWEB nastavit na false a provést kompilaci. Výsledný obraz „<aplikace>_vX.X.X.bin” (vytvořený během procesu kompilace) lze nalézt v adresáři /bin/<aplikace>. Označení verze „X.X.X“ se nastavuje před kompilací v souboru platformio.ini rovněž jako build_flag.

Instalace firmware

Do nového (případně použitého v jiné aplikaci) ESP32 se firmware musí nainstalovat vždy po kabelu. Jsou dvě možnosti. Buď přímo z prostředí VS Code anebo s využitím Flash utility.

Instalace pomocí VS Code

Tento způsob si zvolí zkušení uživatelé, kteří si firmware sami kompilují a mohou si ho tedy i přizpůsobit svým potřebám (ať už pouze pomocí build_flags nebo i zásahem do kódu).

Vzhledem k multi-boot architektuře je postup instalace specifický. Aby se nemusely výchozí env před kompilací a uploadem jednotlivých aplikací přepínat pomocí editace platformio.ini (komentováním řádků v oddílu [platformio]), lze s výhodou používat postranní nabídku Pioarduino: Project Tasks. U uploadu aplikací menu_app a btls_app ani jiná možnost není!

Postup:

1. Pomocí Project Tasks/radio_app/General/Build zkompilovat aplikaci radio_app.
2. Pomocí Project Tasks/radio_app/General/Upload uploadovat obraz aplikace radio_app. Přitom dojde k uploadu nejen binárky aplikace, ale i souborů partitions.bin a bootloader.bin.
3. Pomocí Project Tasks/btls_app/General/Build zkompilovat aplikaci btls_app.
4. Pomocí Project Tasks/btls_app/Custom/Upload custom binary uploadovat obraz aplikace btls_app.
5. Pomocí Project Tasks/menu_app/General/Build zkompilovat aplikaci menu_app.
6. Pomocí Project Tasks/menu_app/Custom/Upload custom binary uploadovat obraz aplikace menu_app.

Pokud vše proběhlo v pořádku, firmware je nainstalovaný. Lze pokračovat podle kapitoly První spuštění.

Instalace pomocí Flash utility

Pro méně zkušené uživatele (kterým stačí předkompilovaný firmware) jsem připravil skript Flash utility.

Upozornění: Před spuštěním instalace se ujistěte, že vybraný COM port nepoužívá jiný program (např. sériový monitor ve VS Code), jinak se esptool.exe k čipu nepřipojí.

Postup instalace (předpokladem je ESP32 připojený USB kabelem k počítači):

1. Stáhnout instalační balíček https://github.com/Pako2/RadioESP32/releases/latest/download/RadioESP32_binaries.zip
2. Stažený balíček rozbalit do vhodné složky – nazvěme ji třeba RadioESP32.
3. Průzkumníkem Windows přejít do zvolené složky (RadioESP32).
4. Spustit (např. poklepáním) soubor flash.bat. Ten automaticky spustí modernější PowerShell skript flash_utility.ps1 (zabezpečení Windows skript bezpečně obejde) a objeví se níže zobrazená nabídka.
5. Doporučený (nepovinný) krok – volba [0] – Perform Chip Erase on SPI flash.
6. Povinný krok – volba [1] – Flash Complete Firmware (pokud byl proveden i krok 5, je třeba znovu spustit flash.bat).

Pokud vše proběhlo v pořádku, firmware je nainstalovaný. Po úspěšném flashování doporučuji odpojit a znovu připojit USB kabel (nebo stisknout tlačítko EN/RST na modulu). Někdy je po uploadu u ESP32 potřeba provést fyzický restart, aby se správně inicializovala tabulka oblastí a LittleFS.
Poznámky:
Volby [2] až [4] nejsou určeny pro fázi prvotní instalace. Pomocí nich lze následně provádět upgrady jednotlivých aplikací (pokud z nějakého důvodu nevyhovuje postup s Update Managerem).

Volba [Q] slouží k bezpečnému ukončení utility, pokud si uživatel flashování rozmyslí.


První spuštění

Jakmile je přístroj poprvé spuštěn, běží ve výchozím nastavení a v režimu AP. Na PC se připojíme k síti „RadioESP32“ a v prohlížeči na adresu 192.168.4.1. Měla by se objevit webová stránka, prostřednictvím které je třeba provést nastavení přístroje. Popis webového rozhraní je v kapitole Hlavní nabídka.

Upgrade

Aplikace Internetové rádio a BT reproduktor mohou být upgradovány velmi snadno prostřednictvím webového rozhraní aplikace Update Manager.

Postup:

a) Z aplikací Internetové rádio a BT reproduktor se lze do aplikace Update Manager přepnout pomocí nabídky na displeji, kterou je možné vyvolat dlouhým stisknutím tlačítka rotačního enkodéru. Druhá možnost je stisknutím SW tlačítka Jump to Update Manager, které se nachází na stránce „Check for updates“. To samozřejmě platí jen pro Internetové rádio.

b) Po úspěšném přepnutí aplikací se místo modrého rozhraní webového serveru Internetového rádia objeví červené rozhraní Update Manageru. Pro vstup do něho je nutné zadat heslo „admin“ (jak je definováno ve zdrojovém textu aplikace Update Manager).

c) V nabídce (na levé straně obrazovky) vybereme položku Update Manager.

d) Objeví se tabulka, která zobrazuje jak aktuální verze aplikací, tak verze dostupné na internetu.

e) Pokud existuje novější verze, než je aktuální, je možné stisknout SW tlačítko Update a potom se řídit pokyny na obrazovce. Výsledkem by měla být upgradovaná aplikace.

Na stejné stránce jsou navíc tlačítka, pomocí nichž lze vytvořit zálohy aktuálních aplikací (bin soubory). Dále je tam i možnost uploadovat (tedy provést i případný downgrade) libovolný jiný bin soubor, který je dostupný na disku počítače.

Upgrade z verze 1.X.X na verzi 2.X.X

Vzhledem k tomu, že architektura obou verzí je zcela odlišná, je nutné provést úplnou instalaci.

Doporučený postup:

1. Zazálohovat konfiguraci (nabídka Backup & Restore)
2. Provést upgrade – například podle kapitoly Instalace pomocí Flash utility
3. Obnovit konfiguraci (nabídka Backup & Restore)

Hlavní nabídka

V levé části obrazovky je vždy hlavní nabídka. Popis položek hlavní nabídky:

Radio Player

Po kliknutí na tuto položku se objeví stránka, pomocí které se dá komfortně ovládat rádio.

SD Card Player

Tato položka se zobrazuje jen v případě, že SW je zkompilován s možností SDCARD.

Po kliknutí na tuto položku se objeví stránka, pomocí které se dají komfortně ovládat funkce přehrávače souborů z SD karty.

Status

Po kliknutí na tuto položku se objeví stránka se základními údaji o přístroji.

Settings

Je-li třeba upravit nastavení přístroje (například při prvním spuštění), vybereme položku Settings. Po kliknutí na ni se nabídka rozbalí a uvidíme devět dílčích nabídek:

###### Radio Settings

Na této stránce se zejména vytváří nabídka rozhlasových stanic. Dále se zde dá nastavit výchozí stanice (ta se vždy automaticky vybere při zapnutí přístroje), výchozí hlasitost a hodnoty jednoduchého ekvalizéru.

###### SD Card Settings

Tato položka se zobrazuje jen v případě, že SW je zkompilován s možností SDCARD. Na této stránce se dá nastavit pouze jeden parametr a tím je "Seek step". To je délka skoku (vpřed i vzad) ve vteřinách. Nastavení výchozí hlasitosti a ekvalizéru, které je na stránce Radio Settings, platí i pro přehrávač souborů z SD karty.

###### Bluetooth Settings

Na této stránce lze nastavit některé vlastnosti BT reproduktoru (například jméno, kterým se BT reproduktor prezentuje).

Network Settings

Na této stránce je třeba nastavit zejména síť (případně více sítí), na kterou se má přístroj připojit. Stiskneme Edit Networks a následně New Network. V dialogovém okně, které se objeví, nastavíme požadované hodnoty. Lze použít tlačítko Scan k vyhledání dostupných sítí. Po nastavení stiskneme Save Changes. Pod tabulkou sítí je možné ještě změnit SSID, IP adresu a masku (vše v AP režimu). Změny je třeba potvrdit stisknutím tlačítka Save a posléze také žlutého tlačítka s textem You have uncommited changes, please click here to commit and reboot …. Toto žluté tlačítko je však vhodné použít teprve až po projití všech ostatních nastavení, protože po jeho použití se přístroj restartuje.

###### Hardware Settings

Na této stránce je možné nastavit některé použité GPIO piny (některé jsou nastaveny před kompilací v platformio.ini) a několik dalších parametrů. Nastavené hodnoty je opět třeba potvrdit stisknutím tlačítka Save.

IR Remote Settings

Na této stránce se konfigurují povely dálkového ovládání. Přidání nového povelu je velmi jednoduché a intuitivní. Nastavené povely je třeba opět třeba potvrdit stisknutím tlačítka Save.


###### Display Settings

Na této stránce je možné nastavit zejména úrovně podsvícení displeje a nastavení zobrazení hodin v klidu. Uživatel si také může pojmenovat dny v týdnu ve svém jazyce (ve výchozím stavu jsou jména anglická). Jako vždy se po všech změnách musí stisknout tlačítko Save.

###### General Settings

Na této stránce je možné nastavit "Jméno stroje" (Host Name) a také se zde kalibruje zobrazování úrovně nabití baterie. Potvrzuje se opět stisknutím tlačítka Save.

###### NTP (Time) Settings

Na této stránce je možné nastavit NTP server, interval synchronizace (v minutách) a časovou zónu. Změny se opět potvrzují stisknutím tlačítka Save.
Někdy se může stát, že v době zapnutí (nebo restartu) přístroje není dostupná žádná ze známých WiFi sítí. Potom samozřejmě není možné synchronizovat čas s NTP serverem. V takové krajní situaci pomůže tlačítko Sync Browser Time to Device.

Backup & Restore

V hlavní nabídce dále nalezneme položku „Backup & Restore“. Význam je zřejmý z názvu. Je možné uložit si do PC soubor se zálohou nastavení a v případě potřeby se ke stejnému nastavení snadno vrátit. Pod uvedenou položkou je umístěna ještě další funkce – reboot přístroje.

Factory reset

Pod touto položkou hlavní nabídky se skrývá stejnojmenná funkce. Po její aktivaci se vymaže konfigurační soubor a po rebootu je přístroj ve stejném stavu jako při prvním spuštění.

Check for updates

Vybereme-li tuto položku, objeví se tabulka s aktuálními a dostupnými verzemi jednotlivých aplikací. Je možné stisknout tlačítko Jump to Update Manager a přepnout se do příslušné aplikace. Další postup byl popsán v kapitole Upgrade.

Ovládání přístroje pomocí rotačního enkodéru

Aplikace Internetové rádio

- V základním režimu se otáčením knoflíku ovládá hlasitost a stisknutím se zapíná/vypíná Mute.
- Dvojitým stiskem knoflíku se přístroj přepne do režimu volby rozhlasové stanice. Seznamem předvoleb se listuje pomocí otáčení knoflíku. Vybranou stanici je třeba potvrdit stisknutím knoflíku.
- Trojitým stiskem knoflíku se přístroj přepne do režimu volby souboru z SD karty. Otáčením knoflíku lze listovat seznamem skladeb. Vybraný soubor je třeba potvrdit stisknutím knoflíku.
- Dlouhým stiskem knoflíku (asi 4 sekundy) lze vyvolat nabídku pro přepínání aplikací. V této nabídce je navíc i položka, jejíž volbou je možné přístroj vypnout.

Aplikace Bluetooth Reproduktor

- V základním režimu se otáčením knoflíku ovládá hlasitost. Funkce přiřazená stisknutí knoflíku může být vybrána v nastavení vlastností BT reproduktoru (přes webové rozhraní rádia). Ve výchozím stavu se stisknutím tlačítka přepíná mezi pause a play. Druhá možnost (kterou je ale třeba zvolit si v konfiguraci) je přepínání stavu Mute.
- Dvojitým stiskem tlačítka se přístroj přepne do režimu „přeskakování“ skladeb (dopředu nebo dozadu). Stisknutím knoflíku zde ve výchozím stavu ovládáno Mute, zatímco druhou možností (kterou je ale třeba zvolit si v konfiguraci) je ovládání pause/play.
- Dlouhým stiskem knoflíku (asi 4 sekundy) lze vyvolat nabídku pro přepínání aplikací. V této nabídce je navíc i položka, jejíž volbou je možné přístroj vypnout.

Aplikace Update Manager

V aplikaci Update Manager se rotačním enkodérem ovládá pouze menu pro volbu aplikací (nebo vypnutí). Žádnou jinou funkci nemá.

Ovládání přístroje infračerveným dálkovým ovládáním

V kapitole Hlavní nabídka/Settings/IR Remote Settings je uvedeno, jakým způsobem lze přístroj naučit povely dálkového ovládání. Povely jsou společné pro aplikaci Internetové rádio (včetně přehrávače SD karty) a aplikaci BT reproduktor. Aplikace Update Manager se pomocí IR ovládat nedá. Ovládání se nijak neliší od ovládání běžných multimediálních přístrojů a není třeba ho nijak detailněji popisovat.
Poznámka:
Při zadávání předvolby číslem není třeba číslo potvrzovat povelem OK – stačí chvilku počkat. Na rozdíl od toho, při zadávání času pro usnutí, zadaný čas je třeba povelem OK potvrdit.

Konstrukce přístroje

Konstrukce je dostatečně popsána v souboru README.md v repozitáři projektu.

K nahlédnutí je na adrese https://github.com/Pako2/RadioESP32/blob/main/README.md .

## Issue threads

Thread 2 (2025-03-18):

some questions

JulesDeChezSmithEnFace, 2025-03-18:
Hi,

i tried to compile your sketch (1.0.5)  and had few issues.
i use an esp32-S3 16rn8.

1) if i comment option " ;-D BATTERY  " it gives the following error when compiling :

src/main.cpp: In function 'void changeDispMode(disp_mode_t)':
src/main.cpp:1526:22: error: 'adcval' was not declared in this scope
      |       uint16_t val = adcval;
      |                      ^~~~~~

2) when i run the sketch , the default json config file seems malformed

[    44][W][main.cpp:2537] setup(): [main] Starting ...
[    51][W][main.cpp:2590] setup(): [main] LittleFS is okay, space 786432, used 12288
[    69][W][loadConfig.h:58] loadConfiguration(): [loadConfig] Failed to parse config file
[    78][E][ESPmDNS.cpp:85] begin(): Failed starting MDNS
[    84][W][webserver.h:7] setupWebServer(): [webserver] Error setting up MDNS responder !

i am not familiar with json file but the problem seems here :

2472 main.cpp  "\"mutepin\":255,"

 its okay with this mod ->    "\"mutepin\":255"

3) on the web interface the 2 buttons to change Radio Stations dont work.

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

4) i use ST7735 , on the display only Radio Station is displayed , no artist and title info.

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

btw the sound is ok.

Pako2, 2025-03-19:
Hi.
First of all, thank you for trying my project and reporting the bugs.
1. Fixed in version 1.0.6
2. Fixed in version 1.0.6
3. Fixed in version 1.0.6
4. Unfortunately, I cannot confirm. The behavior mentioned is normal for some stations that do not provide metadata. Can you please give me a link to the stream where you encountered the problem?

JulesDeChezSmithEnFace, 2025-03-19:
Hi,
Thanks for version 1.0.6 , as you wrote 1/2/3 were fixed.

see below the log during playing stations :

Radio Paradise   http://stream-uk1.radioparadise.com/aac-320

[150559][W][main.cpp:3491] loop(): [main] Free heap, free stack: 174488, 836
[150568][W][wsResponses.h:56] sendHeartBeat(): [wsResponses] Heartbeat message sent !
[155559][W][main.cpp:3491] loop(): [main] Free heap, free stack: 174488, 836
[155568][W][wsResponses.h:56] sendHeartBeat(): [wsResponses] Heartbeat message sent !
I2S AUDIO_INFO        StreamTitle='Nick Drake - One of These Things First'
[157801][W][main.cpp:924] audio_showstreamtitle(): [main]  : "Nick Drake - One of These Things First"
I2S AUDIO_INFO        StreamUrl='http://img.radioparadise.com/covers/l/B000025H0Q.jpg'
[160550][W][main.cpp:3491] loop(): [main] Free heap, free stack: 174368, 836

On Charts	http://0n-charts.radionetz.de:8000/0n-charts.mp3

[230550][W][main.cpp:3491] loop(): [main] Free heap, free stack: 174488, 836
[230559][W][wsResponses.h:56] sendHeartBeat(): [wsResponses] Heartbeat message sent !
[235550][W][main.cpp:3491] loop(): [main] Free heap, free stack: 174476, 836
[235559][W][wsResponses.h:56] sendHeartBeat(): [wsResponses] Heartbeat message sent !
[237164][W][main.cpp:1743] setPreset(): [main] Preset is [2] : http://0n-charts.radionetz.de:8000/0n-charts.mp3
I2S AUDIO_INFO        buffers freed, free Heap: 176208 bytes
I2S AUDIO_INFO        connect to: "0n-charts.radionetz.de" on port 8000 path "/0n-charts.mp3"
I2S AUDIO_INFO        Connection has been established in 40 ms, free Heap: 175572 bytes
I2S AUDIO_INFO        MP3Decoder has been initialized, free Heap: 174404 bytes , free stack 1316 DWORDs
I2S AUDIO_INFO        stream ready
I2S AUDIO_INFO        syncword found at pos 0
I2S AUDIO_INFO        MPEG-2.5, Layer I
I2S AUDIO_INFO        Channels: 2
I2S AUDIO_INFO        SampleRate: 44100
I2S AUDIO_INFO        BitsPerSample: 16
I2S AUDIO_INFO        BitRate: 128000
I2S AUDIO_INFO        StreamTitle='Tom Gregory - River '
[237984][W][main.cpp:924] audio_showstreamtitle(): [main]  : "Tom Gregory - River "
[240559][W][main.cpp:3491] loop(): [main] Free heap, free stack: 174376, 836
[240568][W][wsResponses.h:56] sendHeartBeat(): [wsResponses] Heartbeat message sent !
[245550][W][main.cpp:3491] loop(): [main] Free heap, free stack: 174476, 836

Radio Monster	http://tophits.radiomonster.fm/320.mp3

[305559][W][wsResponses.h:56] sendHeartBeat(): [wsResponses] Heartbeat message sent !
[310550][W][main.cpp:3491] loop(): [main] Free heap, free stack: 174476, 836
[310559][W][wsResponses.h:56] sendHeartBeat(): [wsResponses] Heartbeat message sent !
[315550][W][main.cpp:3491] loop(): [main] Free heap, free stack: 174464, 836
[315560][W][wsResponses.h:56] sendHeartBeat(): [wsResponses] Heartbeat message sent !
[316788][W][main.cpp:1760] updatePreset(): [main] Requested preset = 1
[316796][W][main.cpp:1743] setPreset(): [main] Preset is [1] : http://tophits.radiomonster.fm/320.mp3
I2S AUDIO_INFO        buffers freed, free Heap: 176000 bytes
I2S AUDIO_INFO        connect to: "tophits.radiomonster.fm" on port 80 path "/320.mp3"
I2S AUDIO_INFO        Connection has been established in 48 ms, free Heap: 175772 bytes
I2S AUDIO_INFO        redirect to new host "http://ic.radiomonster.fm/tophits.ultra"
I2S AUDIO_INFO        buffers freed, free Heap: 176040 bytes
I2S AUDIO_INFO        connect to: "ic.radiomonster.fm" on port 80 path "/tophits.ultra"
I2S AUDIO_INFO        Connection has been established in 30 ms, free Heap: 175844 bytes
I2S AUDIO_INFO        MP3Decoder has been initialized, free Heap: 174404 bytes , free stack 1316 DWORDs
I2S AUDIO_INFO        stream ready
I2S AUDIO_INFO        syncword found at pos 0
I2S AUDIO_INFO        MPEG-2.5, Layer I
I2S AUDIO_INFO        Channels: 2
I2S AUDIO_INFO        SampleRate: 44100
I2S AUDIO_INFO        BitsPerSample: 16
I2S AUDIO_INFO        BitRate: 320000
I2S AUDIO_INFO        StreamTitle='NLE Choppa, Imagine Dragons - Dare U'
[317391][W][main.cpp:924] audio_showstreamtitle(): [main]  : "NLE Choppa, Imagine Dragons - Dare U"
[320550][W][main.cpp:3491] loop(): [main] Free heap, free stack: 174420, 836
[320559][W][wsResponses.h:56] sendHeartBeat(): [wsResponses] Heartbeat message sent !
[325550][W][main.cpp:3491] loop(): [main] Free heap, free stack: 174476, 836

- the display on st7735 stay stuck on the first radio station name selected during boot.

- the volume bar display doesnt move while moving encoder , but the volume change according
and the mute fonction is okay.

- on the web interface the volume bar and mute status are updated correctly.

on the web interface when changing radio station , the artist and title are updated and displayed correctly.

Thank you !

JulesDeChezSmithEnFace, 2025-03-21:
Hi,

i followed your advice with the followind mods :

1)  #define TFT_MISO 13

2) TFT_eSPI_ESP32_S3.h:

#include "driver/spi_master.h"
#include "hal/gpio_ll.h"
add==>  #include "soc/soc.h"

3) moved modification in TFT_eSPI_ESP32_S3.c to here:

void IRAM_ATTR dma_end_callback(spi_transaction_t *spi_tx)
{
...
...
WRITE_PERI_REG( SPI_DMA_CONF_REG(SPI_DMA_CH_AUTO) , 0b11 );  //workaround
// WRITE_PERI_REG(SPI_DMA_CONF_REG(spi_host), 0);
}

and the display works like a charm !

Thank you !!!

Pako2, 2025-03-23:
Well, that's really great. You made me very happy. I'm especially glad that your time, which you invested in my project with trust, was not wasted. I hope that you will actually use the radio you built and that it will make you happy.

Pako2, 2025-05-22:
@[JulesDeChezSmithEnFace](https://github.com/JulesDeChezSmithEnFace):
Hi!
You might be interested to know that I just published a "new" project [RadioESP32S3](https://github.com/Pako2/RadioESP32S3). It's basically the same as this **RadioESP32** project, but - as the name suggests - it's modified for the S3 version of the ESP32 chip.
BTW - are you using it? What are your experiences?

Closed 2025-03-21.

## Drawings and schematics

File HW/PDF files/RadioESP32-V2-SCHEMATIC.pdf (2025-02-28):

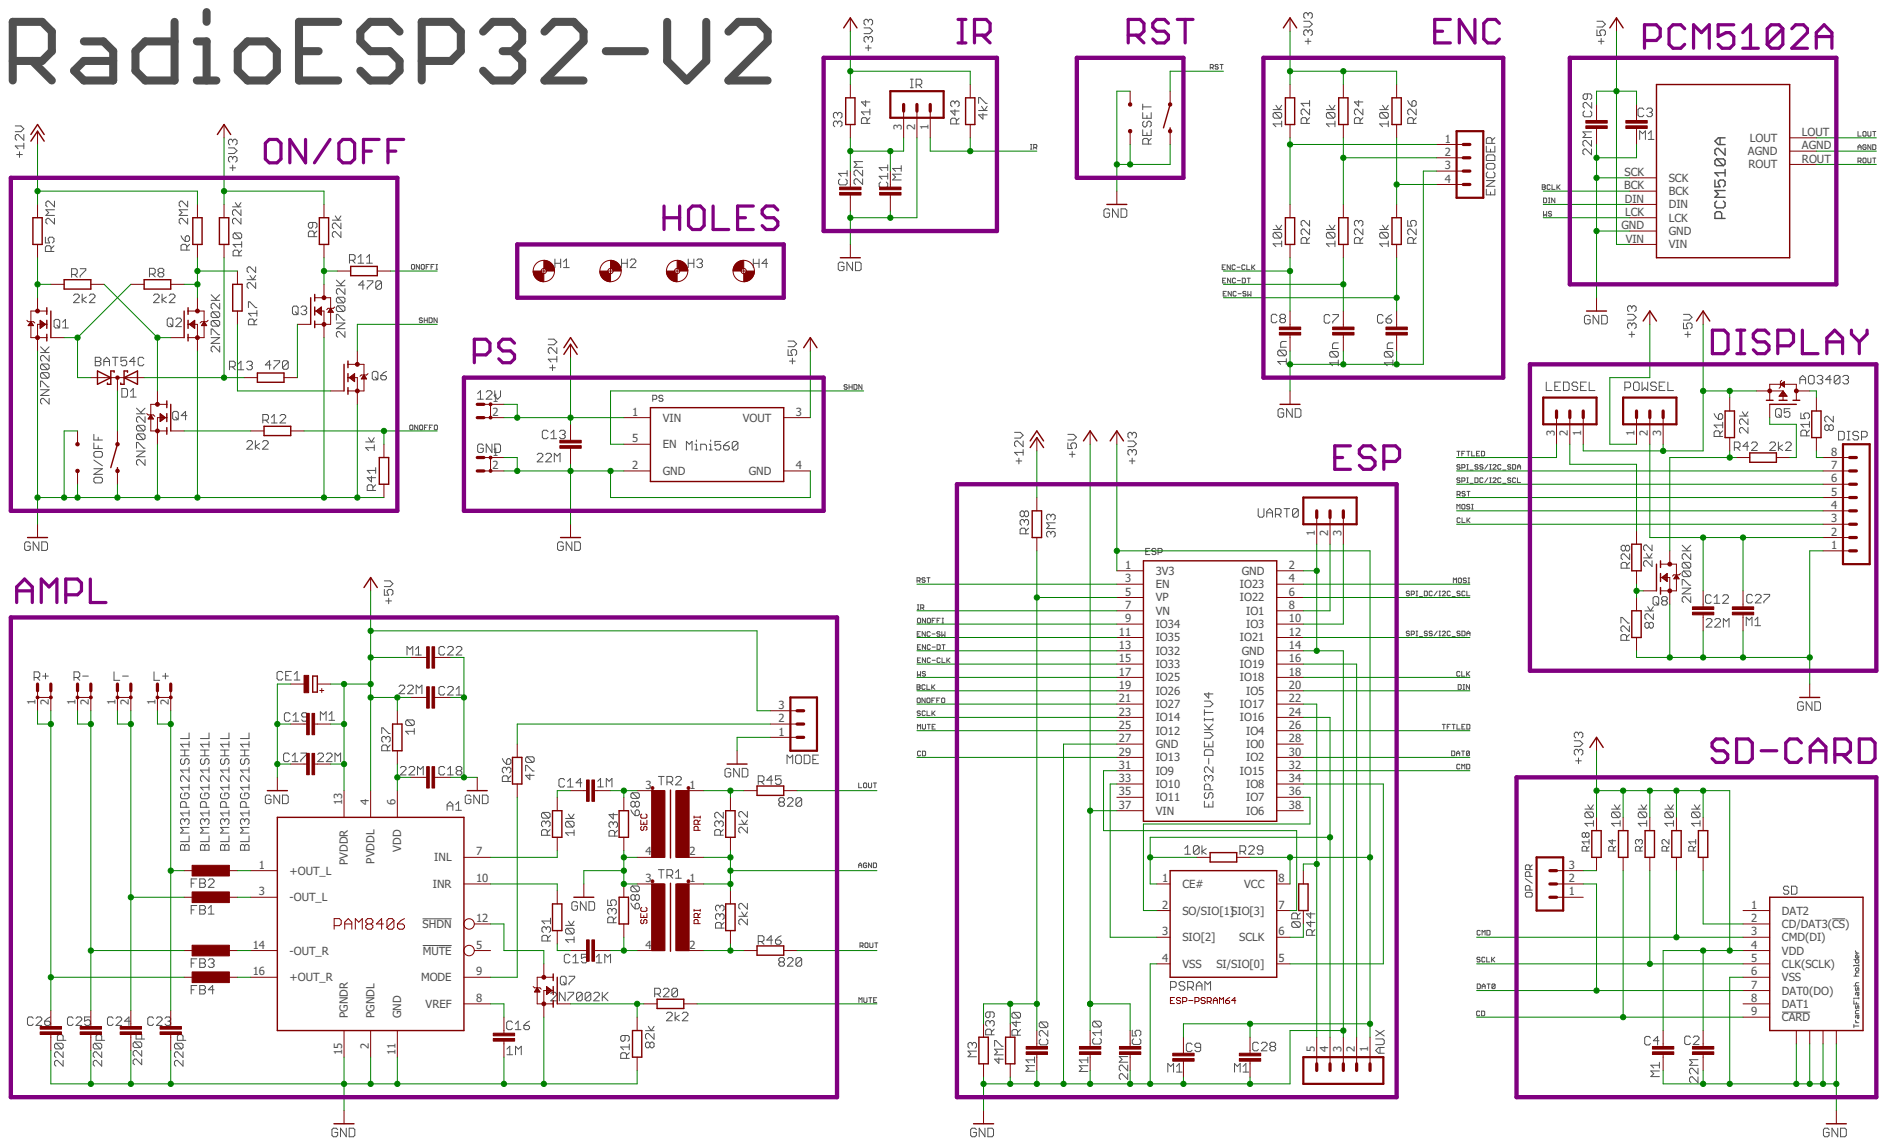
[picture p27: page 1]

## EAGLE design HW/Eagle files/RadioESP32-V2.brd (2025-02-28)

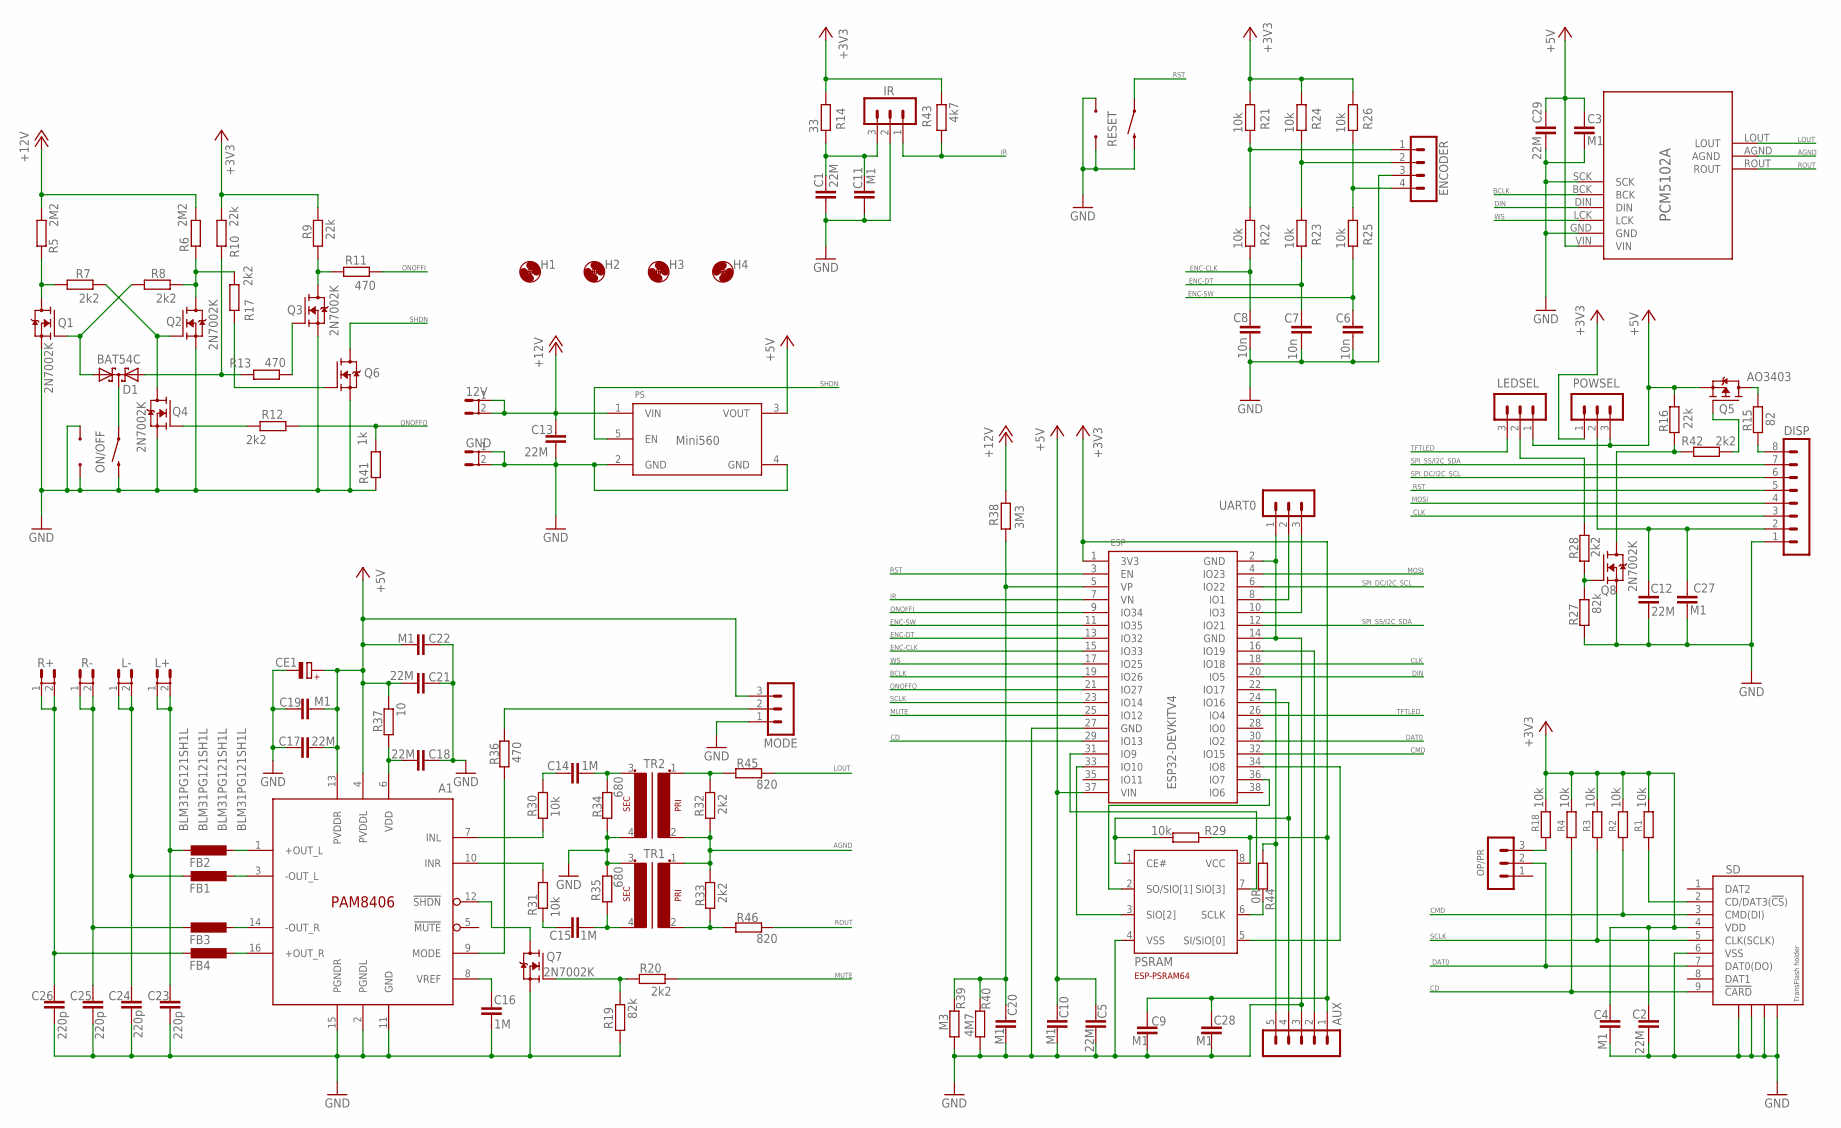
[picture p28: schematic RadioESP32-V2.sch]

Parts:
12V: FASTON; FASTON4.8
A1: PAM8406; SOP-16
AUX: CON-LSTB_MA05-108; CON-LSTB_MA05-1-NS08
C1, C2, C5, C12, C13, C17, C18, C21, C29: 22M; C1206K
C3, C4, C9, C10, C11, C19, C20, C22, C27, C28: M1; C0805
C6, C7, C8: 10n; C0805
C14, C15, C16: 1M; C1206K
C23, C24, C25, C26: 220p; C0805
CE1: CPOL; E5-10.5
D1: BAT54C; SOT23
DISP: CON-LSTB_MA08-108; CON-LSTB-MA08-1-NS08
ENCODER: CON-LSTB_MA04-108; CON-LSTB_MA04-1-NS08
ESP: ESP32-DEVKITV4_ESP32DEVKITV4NOTXT; ESP32_DEVKIT_V4
FB1, FB2, FB3, FB4: BLM31PG121SH1L; C1206K
GND: FASTON; FASTON4.8
H1, H2, H3, H4: MOUNT-HOLE3.0; 3,0
IR: CON-LSTB_MA03-108; CON-LSTB_MA03-1-NS08
L+: FASTON; FASTON4.8
L-: FASTON; FASTON4.8
LEDSEL: CON-LSTB_MA03-108; CON-LSTB_MA03-1-NS08
MODE: CON-LSTB_MA03-108; CON-LSTB_MA03-1-NS08
ON/OFF: MOMENTARY-SWITCH-SPST1; TACTILE_SWITCH_ANGLE-NS1
OP/PR: CON-LSTB_MA03-108; CON-LSTB_MA03-1-NS08
PCM5102A: PCM5102A_MODULE
POWSEL: CON-LSTB_MA03-108; CON-LSTB_MA03-1-NS08
PS: MINI560EXT; MINI560-NS-EXT
PSRAM: PSRAM; SOT23-8-W
Q1, Q2, Q3, Q4, Q6, Q7, Q8: 2N7002K; TRANSISTOR-FET_SOT23
Q5: AO3403; SOT23
R1, R2, R3, R4, R18, R21, R22, R23, R24, R25, R26, R29, R30, R31: 10k; R0805
R5, R6: 2M2; R0805
R7, R8, R12, R17, R20, R28, R32, R33, R42: 2k2; R0805
R9, R10, R16: 22k; R0805
R11, R13, R36: 470; R0805
R14: 33; R0805
R15: 82; R1206
R19, R27: 82k; R0805
R34, R35: 680; R0805
R37: 10; R0805
R38: 3M3; R0805
R39: M3; R0805
R40: 4M7; R0805
R41: 1k; R0805
R43: 4k7; R0805
R44: 0R; R0805
R45, R46: 820; R0805
R+: FASTON; FASTON4.8
R-: FASTON; FASTON4.8
RESET: MOMENTARY-SWITCH-SPST1; TACTILE_SWITCH_ANGLE-NS1
SD: SD-MMC_TF-HOLDER; SD-MMC_TF-PULL
TR1, TR2: AUDIOTRAFONS2; AUDIOTRAFO_2-NS
UART0: CON-LSTB_MA03-108; CON-LSTB_MA03-1-NS08

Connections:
+3V3: AUX.1, C2.2, C4.2, C9.2, C28.2, ESP.1 (3V3), POWSEL.1, PSRAM.8 (VCC), R1.2, R2.2, R3.2, R4.2, R9.2, R10.2, R14.2, R18.2, R21.2, R24.2, R26.2, R29.1, R43.1, SD.4 (VDD)
+5V: A1.4 (PVDDL), A1.13 (PVDDR), C3.1, C5.1, C10.1, C17.2, C19.2, C21.1, C22.1, C29.2, CE1.+, CE1.++ (+), ESP.37 (VIN), LEDSEL.1, MODE.3, PCM5102A.VIN, POWSEL.3, PS.3 (VOUT), Q5.2 (S), R16.2, R37.1
+12V: 12V.1, 12V.2, C13.2, PS.1 (VIN), R5.2, R6.2, R38.2
AGND: PCM5102A.AGND, R32.1, R33.2, TR1.1, TR2.2
BCLK: ESP.19 (IO26), PCM5102A.BCK
CD: ESP.29 (IO13), R4.1, SD.9 (!CARD)
CLK: DISP.3, ESP.18 (IO18)
CMD: ESP.32 (IO15), R2.1, SD.3 (CMD(DI))
DAT0: ESP.30 (IO2), OP/PR.2, SD.7 (DAT0(DO))
DIN: ESP.20 (IO5), PCM5102A.DIN
ENC-CLK: C8.1, ESP.15 (IO33), R22.1
ENC-DT: C7.1, ESP.13 (IO32), R23.1
ENC-SW: C6.1, ESP.11 (IO35), R25.1
GND: A1.2 (PGNDL), A1.11 (GND), A1.15 (PGNDR), AUX.3, C1.2, C2.1, C3.2, C4.1, C5.2, C6.2, C7.2, C8.2, C9.1, C10.2, C11.2, C12.1, C13.1, C16.1, C17.1, C18.2, C19.1, C20.1, C21.2, C22.2, C23.1, C24.1, C25.1, C26.1, C27.2, C28.1, C29.1, CE1.-, DISP.1, ENCODER.3 (4), ESP.2 (GND), ESP.14 (GND), ESP.27 (GND), GND.1, GND.2, IR.2, MODE.1, ON/OFF.2, ON/OFF.A1, ON/OFF.A2, PCM5102A.GND, PCM5102A.SCK, PS.2 (GND), PS.4 (GND), PSRAM.4 (VSS), Q1.2 (S), Q2.2 (S), Q3.2 (S), Q4.2 (S), Q6.2 (S), Q7.2 (S), Q8.2 (S), R19.2, R27.2, R34.1, R35.2, R39.1, R40.1, R41.1, RESET.2, RESET.A1, RESET.A2, SD.6 (VSS), SD.S1, SD.S2, SD.S3, SD.S4, TR1.3 (S1), TR2.4 (S2), UART0.1
IR: ESP.7 (VN), IR.1, R43.2
LEDA: DISP.8, R15.1
LOUT: PCM5102A.LOUT, R45.2
MOSI: DISP.4, ESP.4 (IO23)
MUTE: ESP.25 (IO12), R20.1
N31: D1.2 (A2), R10.1, R13.2
unnamed: ESP.36 (IO7), PSRAM.2 (SO/SIO[1])
unnamed: ESP.34 (IO8), PSRAM.5 (SI/SIO[0])
unnamed: C14.1, R34.2, TR2.3 (S1)
unnamed: C15.2, R35.1, TR1.4 (S2)
unnamed: C14.2, R30.2
unnamed: A1.7 (INL), R30.1
unnamed: C15.1, R31.2
unnamed: A1.10 (INR), R31.1
unnamed: C1.1, C11.1, IR.3, R14.1
unnamed: Q2.3 (D), R6.1, R8.1, R17.1
unnamed: Q7.1 (G), R19.1, R20.2
unnamed: ESP.33 (IO10), PSRAM.3 (SIO[2])
unnamed: ESP.31 (IO9), PSRAM.7 (SIO[3])
unnamed: Q3.1 (G), R13.1
unnamed: R1.1, SD.2 (CD/DAT3(!CS!))
unnamed: Q1.3 (D), R5.1, R7.2
unnamed: Q5.1 (G), R42.1
unnamed: D1.3 (CC), ON/OFF.1
unnamed: Q2.1 (G), Q4.3 (D), R7.1
unnamed: D1.1 (A1), Q1.1 (G), R8.2
unnamed: Q4.1 (G), R12.2
unnamed: AUX.4, ESP.24 (IO16), PSRAM.1 (CE#), R29.2
unnamed: Q3.3 (D), R9.1, R11.2
unnamed: PSRAM.6 (SCLK), R44.2
unnamed: AUX.2, ESP.16 (IO19)
unnamed: C12.2, C27.1, DISP.2, POWSEL.2
unnamed: R32.2, R45.1, TR2.1
unnamed: A1.8 (VREF), C16.2
unnamed: A1.12 (!SHDN), Q7.3 (D)
unnamed: A1.9 (MODE), R36.1
unnamed: MODE.2, R36.2
unnamed: C23.2, FB2.2, L+.1, L+.2
unnamed: R33.1, R46.1, TR1.2
unnamed: C25.2, FB3.2, R-.1, R-.2
unnamed: C26.2, FB4.2, R+.1, R+.2
unnamed: A1.1 (+OUT_L), FB2.1
unnamed: A1.3 (-OUT_L), FB1.1
unnamed: A1.14 (-OUT_R), FB3.1
unnamed: A1.16 (+OUT_R), FB4.1
unnamed: Q5.3 (D), R15.2
unnamed: Q8.3 (D), R16.1, R42.2
unnamed: OP/PR.3, R18.1
unnamed: C20.2, ESP.5 (VP), R38.1, R39.2, R40.2
unnamed: Q6.1 (G), R17.2
unnamed: C24.2, FB1.2, L-.1, L-.2
unnamed: ENCODER.4 (5), R25.2, R26.1
unnamed: ENCODER.2 (3), R23.2, R24.1
unnamed: ENCODER.1 (2), R21.1, R22.2
unnamed: Q8.1 (G), R27.1, R28.1
ONOFFI: ESP.9 (IO34), R11.1
ONOFFO: ESP.21 (IO27), R12.1, R41.2
ROUT: PCM5102A.ROUT, R46.2
RST: DISP.5, ESP.3 (EN), RESET.1
RX: ESP.10 (IO3), UART0.3
SCLK: ESP.23 (IO14), R3.1, SD.5 (CLK(SCLK))
SHDN: PS.5 (EN), Q6.3 (D)
SPI_DC/I2C_SCL: DISP.6, ESP.6 (IO22)
SPI_SS/I2C_SDA: DISP.7, ESP.12 (IO21)
TFTG: LEDSEL.2, R28.2
TFTLED: ESP.26 (IO4), LEDSEL.3
TX: ESP.8 (IO1), UART0.2
VDD: A1.6 (VDD), C18.1, R37.2
WS: ESP.17 (IO25), PCM5102A.LCK
XDCS: AUX.5, ESP.22 (IO17), R44.1

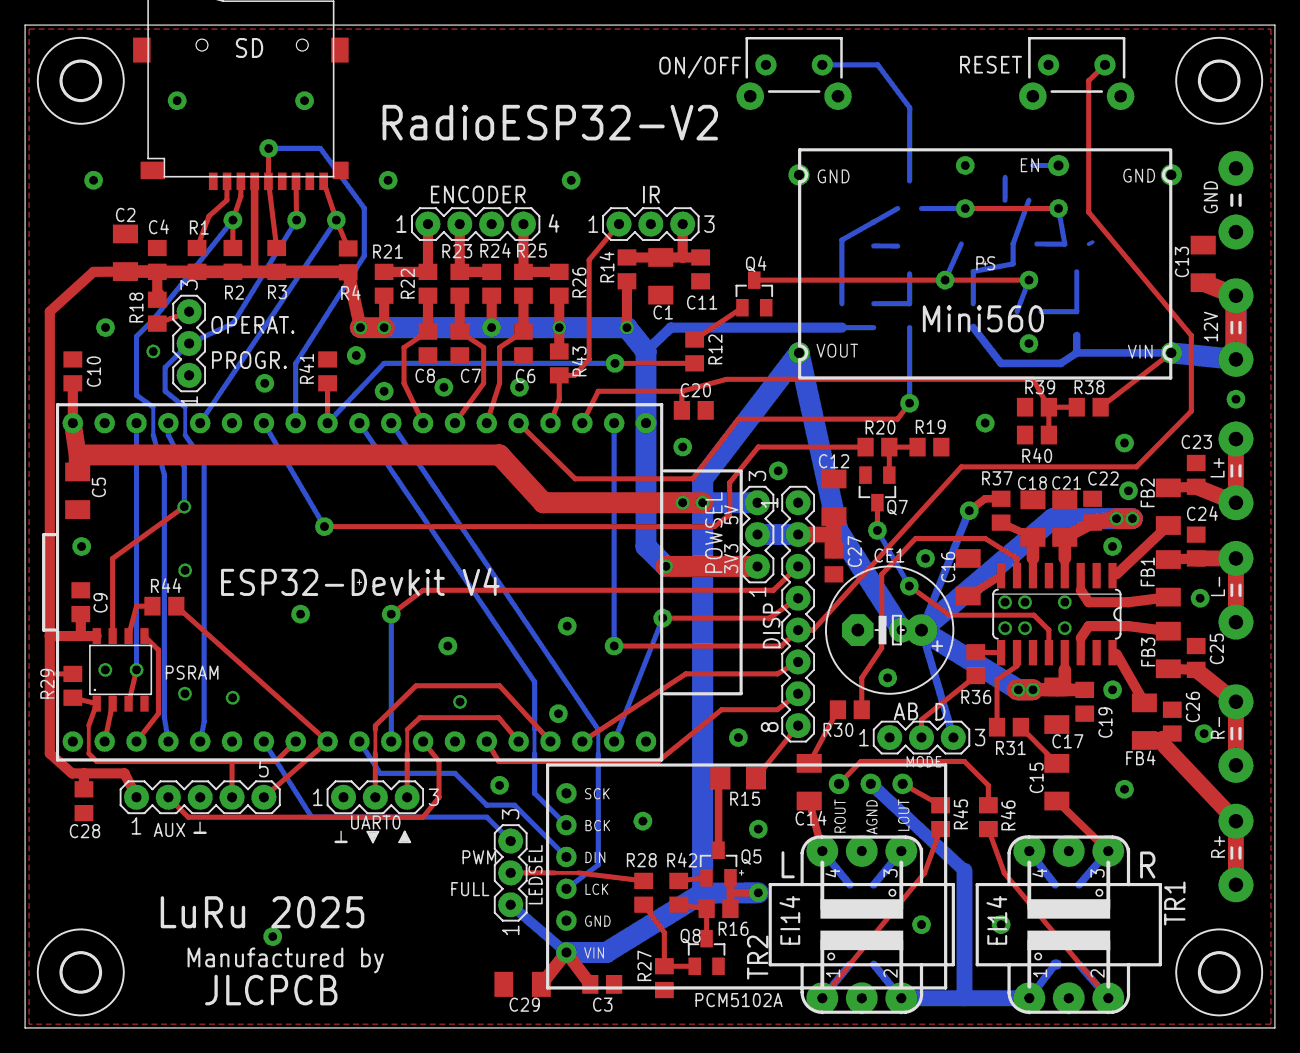
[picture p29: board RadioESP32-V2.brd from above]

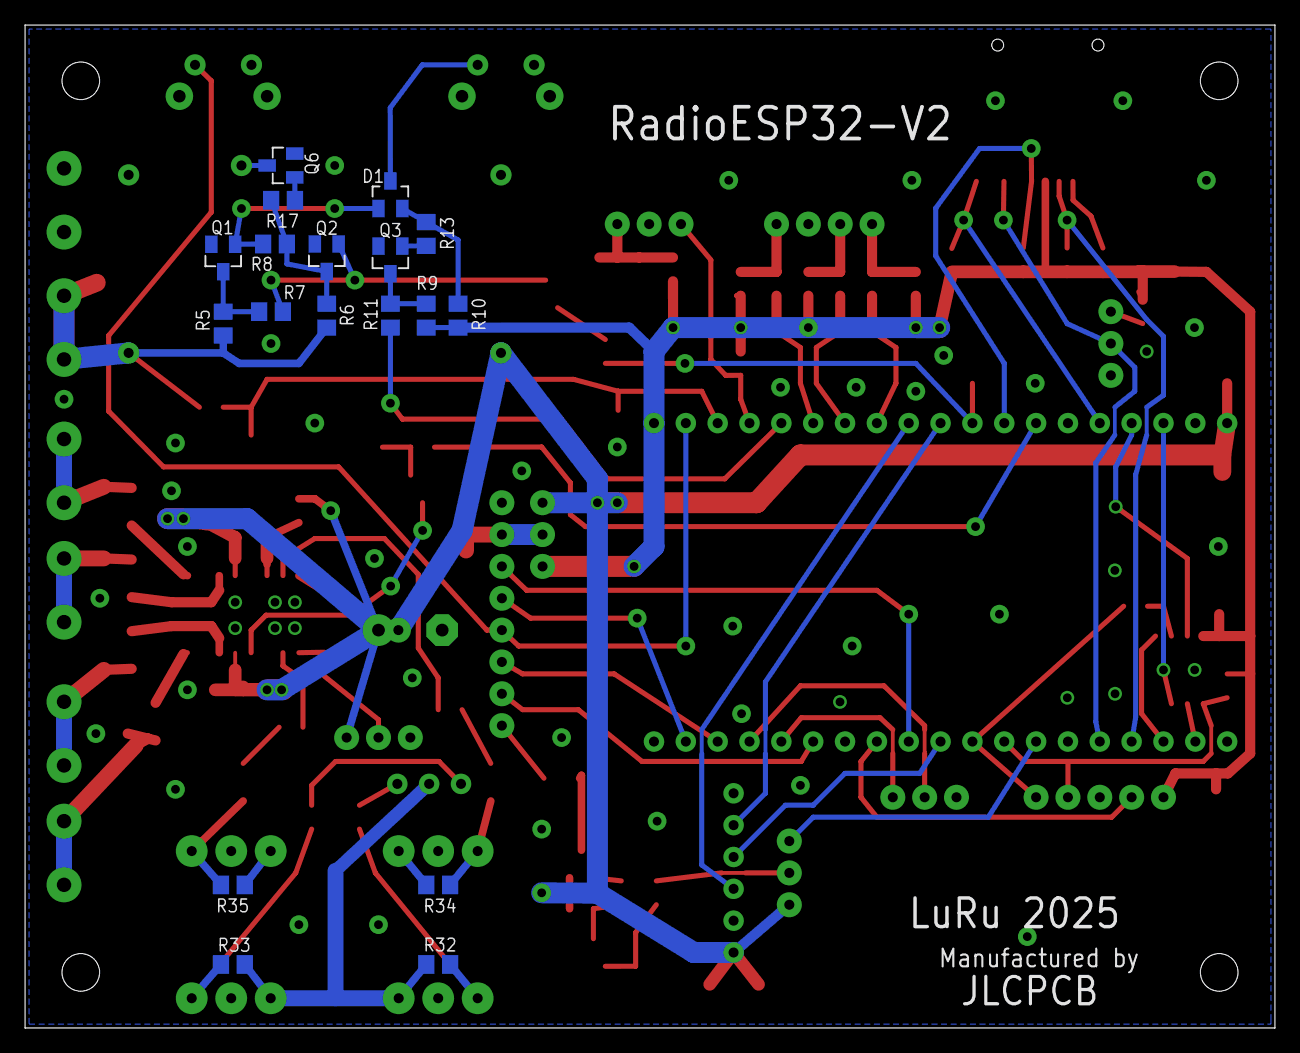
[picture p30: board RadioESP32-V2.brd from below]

Board: 2 copper layers, 99.7 x 80.0 mm, 118 parts (18 on the bottom side), 84 nets.

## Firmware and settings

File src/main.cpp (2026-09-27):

#define MYSTR(A) #A
#define STRINGIFY(A) MYSTR(A)
#define REPLACEMENTCHARACTER '*'
#define sv_ DRAM_ATTR static volatile

#include "Arduino.h"
#include "WiFi.h"
#include <ArduinoJson.h>
#define NO_LED_FEEDBACK_CODE        // saves 92 bytes program memory
#define EXCLUDE_UNIVERSAL_PROTOCOLS // Saves up to 1000 bytes program memory.
#define EXCLUDE_EXOTIC_PROTOCOLS    // saves around 650 bytes program memory if all other protocols are active
#include <ESPAsyncWebServer.h>
#include <IRremote.hpp>
#include "Audio.h"
Audio audio;
#include "HW_Manager.h"
Config *config;
#if defined(AUTOSHUTDOWN)
bool fade_req = false; // Set fade requested
#endif
#include "display.h"
#include <Wire.h>
#include <ESPmDNS.h>
#include <AsyncTCP.h>
#include <freertos/task.h>
#include <esp_task_wdt.h>
#include "esp_ota_ops.h"
#include "esp_system.h"
#include "esp_partition.h"
#include "nvs_flash.h"
#include "esp_wifi.h"

#include <LittleFS.h>
#if DATAWEB
#include <FS_editor.h>
#else
// from vendors - fix
#include "webh/radio_app/glyphicons-halflings-regular.woff.gz.h"
#include "webh/radio_app/required.css.gz.h"
#include "webh/radio_app/required.js.gz.h"
// custom, can be updated and changed - generated from files in the LittleFS partition using Custom scripts
#include "webh/radio_app/radioesp32.js.gz.h"
#include "webh/radio_app/radioesp32.html.gz.h"
#include "webh/radio_app/index.html.gz.h"
#endif
#include <time.h>
#include "esp_sntp.h"
#include "esp_log.h"

// Enums and structs
enum mode_wifi
{
  WF_NONE,
  WF_STA,
  WF_WAITSTA
};
mode_wifi WF_MODE = WF_NONE;

struct WLAN
{
  char name[17];
  uint8_t bssid[6];
  char pass[33];
  char ssid[33];
  uint8_t dhcp;
  IPAddress ipaddress;
  IPAddress subnet;
  IPAddress dnsadd;
  IPAddress gateway;
};

struct PRESET
{
  uint8_t nr = 255; // qsort !!!
  char name[33];
  char url[97];
};

#if defined(SDCARD)
bool sdin = false;
bool oldsdin = false;
#endif

// Forward declaration
void WiFiEvent(WiFiEvent_t, arduino_event_info_t);
void jumptoupman();

#if defined(SDCARD)
void Random();
void Repeat();
void updateTrack(int8_t trckstep);
void setTrack(int16_t trck);
void pausePlay();
void handle_mp3list(AsyncWebServerRequest *request);
#endif
void setPreset(uint8_t prst);
void updatePreset(int8_t prsstep, bool play);
void setMutepin(uint8_t mute_, bool test);
void mute(bool source);
void testUrl(const char *url);
void updateLine(uint8_t row, char *input);

// Global variables
#if defined(SDCARD)
uint32_t pastpos = 0xFFFFFFFF;
uint8_t poscounter = 0;
#endif
bool sdp_icons_req = false;
bool toggle_req = false;
//uint32_t rollbacktimer = 0;

const char SPACES[33] = "                                ";
char *shorttrname;
uint32_t lastblick;
bool coloncolor = false;
uint32_t textcolor = 1;
uint32_t backcolor = 0;
char olddatetxt[16]; // Converted timeinfo/date

struct WLAN *wlans;
struct PRESET *presets;

#if defined(AUTOSHUTDOWN)
const uint8_t cmd_table_len = 29;
#else
const uint8_t cmd_table_len = 27;
#endif
uint8_t *RESERVEDGPIOS;
char *testurl;
int Weekday;
uint8_t presetnum = 0;
uint8_t wlannum = 0;
bool shouldReboot = false;
bool formatreq = false;

/*
Username and password are used in two cases:
============================================
1. to enter the website editor
2. to enter the Update Manager
*/
const char *http_username = "admin";
const char *http_password = "admin";

TaskHandle_t Task0, xsdtask, maintask;

#define FSIF true // Format LittleFS if not existing
bool STAmode = true;
bool APstart = false;
bool gotIP = false;
uint8_t scanmode = 0;
unsigned long digtime = 0;
uint16_t dgt_cmd; // Buffer for digit input

#if defined(AUTOSHUTDOWN)
uint16_t dgt_asd;          // Buffer for digit input for AUTOSHUTDOWN
uint8_t dgt_count_asd = 0; // Digit input count
#define MAXPWOFF 100
#define MINPWOFF 1
uint32_t lastfade = 0;
uint16_t pwoffminutes = MAXPWOFF; // Current power off [minutes] duration
time_t now;
#endif
uint8_t presetReq = 255;
bool testurlFlag = false;
uint16_t reqpreset = 255;
uint16_t audpreset = 255;
bool reconnect = false;
bool rcnnct = false;
bool scanfinished = false;
int16_t nets;
AsyncWebServer server(80);
AsyncWebSocket weso("/ws");

#if defined(SDCARD)
int SD_curindex = 0;     // Current index in mp3names
int SD_ix = 0;           // work index in mp3names
bool SD_okay = false;    // SD is okay
bool SD_mounted = false; // SD is mounted
int SD_filecount = 0;    // Number of filenames in SD_nodelist
int SD_oldindex = 0;
bool sdready_req = false;
bool oldsdix_req = false;
#endif

bool updatemetadata = false;
bool updatealbum = false;
bool updateartist = false;
bool updatetitle = false;
uint8_t messageid = 0;

bool config_req = false;

#include "configManager.h"
#include "wsResponses.h"
#include "websocket.h"
#include "webserver.h"
#if defined(SDCARD)
#include "SDcard.h" // For SD card interface
#endif

const char *TAG = "main"; // For debug lines

char timetxt[9];  // Converted timeinfo
char datetxt[16]; // Converted timeinfo/date

struct tm timeinfo; // Will be filled by NTP server
unsigned long currentMillis = 0;

// Rotary encoder stuff
int16_t enc_preset = 0; // Selected preset

int playingtime = 0;
#if defined(SDCARD)

bool getStopped()
{
  return ((audio.getAudioFileDuration() == 0) && !audio.isRunning());
}

//**************************************************************************************************
//                                        C B  _ M P 3 L I S T                                     *
//**************************************************************************************************
// Callback function for handle_mp3list, will be called for every chunk to send to client.         *
// If no more data is available, this function will return 0.                                      *
//**************************************************************************************************
size_t cb_mp3list(uint8_t *buffer, size_t maxLen, size_t index)
{
  static int i;             // Index in track list
  static const char *path;  // Pointer in file path
  size_t len = 0;           // Number of bytes filled in buffer
  char *p = (char *)buffer; // Treat as pointer to aray of char
  static bool eolSeen;      // Remember if End Of List

  if (index == 0) // First call for this page?
  {
    path = getSDFileName(0);     // Yes, make trackfile seek and get FIRST path from list
    strcpy(fullName, path);      // Copy first path to fullName
    eolSeen = (path == nullptr); // Any file?
    i = 1;                       // Set index (track number) for second track
  }
  while ((maxLen > len) && (!eolSeen)) // Space for another char from path?
  {
    if (*path) // End of path?
    {
      *p++ = *path++; // No, add another character to send buffer
      len++;          // Update total length
    }
    else
    {
      // End of path
      if (i) // At least one path in output?
      {
        *p++ = '\n'; // Yes, add separator
        len++;       // Update total length
      }
      path = getNextEntry();
      i++;
      if (i > SD_filecount) // No more files?
      {
        eolSeen = true; // Yes, stop
        break;
      }
    }
  }
  // We arrive here if output buffer is completely full or end of tracklist is reached
  return len; // Return filled length of buffer
}

//**************************************************************************************************
//                                    H A N D L E _ M P 3 L I S T                                  *
//**************************************************************************************************
// Called from mp3play page to list all the MP3 tracks.                                            *
// It will handle the chunks for the client.  The buffer is filled by the callback routine.        *
//**************************************************************************************************
void handle_mp3list(AsyncWebServerRequest *request)
{
  AsyncWebServerResponse *response;
  response = request->beginChunkedResponse("text/plain", cb_mp3list);
  response->addHeader("Server", config->hostnm);
  request->send(response);
}
#endif

uint8_t getPresetByNr(uint32_t val)
{
  for (uint8_t i = 0; i < presetnum; i++)
  {
    if (presets[i].nr == val)
    {
      return i;
    }
  }
  return 255;
}

#if defined(SDCARD)
void Random()
{
  if (pmode == PM_SDCARD)
  {
    random_ = !random_; // Toggle random play
    if (random_)
    {
      drawIcon(PI_RANDOM);
    }
    else
    {
      if (loop_)
      {
        drawIcon(PI_REPEAT);
      }
      else
      {
        clearIcons(5);
      }
    }
    sendRndLoop();
  }
}

void Repeat()
{
  if (!random_)
  {
    loop_ = !loop_;
    if (loop_)
    {
      drawIcon(PI_REPEAT);
    }
    else
    {
      clearIcons(5);
    }
    sendRndLoop();
  }
}
#endif

// cleanText is used only in the case of the station name during the URL test from the WEB !!!
void cleanText(char *txt)
{
  uint8_t val;
  uint8_t skip = 0;
  char *p = txt;
  for (uint8_t i = 0; i < strlen(txt); i++)
  {
    if (skip > 0)
    {
      skip--;
      p++;
      continue;
    }
    val = (uint8_t)*p;
    if ((val & 0b10000000) == 0) // One-byte utf-8 char
    {
      p++;
      continue;
    }
    if (((val & 0b11100000) == 0b11000000) && ((uint8_t)*(p + 1) > 0x7F)) // Two-bytes utf-8 char
    {
      skip = 1;
      p++;
      continue;
    }
    if (((val & 0b11110000) == 0b11100000) && ((uint8_t)*(p + 1) > 0x7F) && ((uint8_t)*(p + 2) > 0x7F)) // Three-bytes utf-8 char
    {
      skip = 2;
      p++;
      continue;
    }
    if (((val & 0b11110000) == 0b11110000) && ((uint8_t)*(p + 1) > 0x7F) && ((uint8_t)*(p + 2) > 0x7F) && ((uint8_t)*(p + 3) > 0x7F)) // Four-bytes utf-8 char
    {
      skip = 3;
      p++;
      continue;
    }
    if (val > 0x7F)
    {
      *p = REPLACEMENTCHARACTER;
    }
    p++;
  }
}

void show_station(char *info)
{
  updateLine(0, info);
}

void show_artist(char *info)
{
  if (enc_menu_mode == VOLUME)
  {
    updateLine(1, info);
  }
}

void show_title(char *info)
{
  if (enc_menu_mode == VOLUME)
  {
    updateLine(2, info);
  }
}

void audio_id3data(const char *info)
{
#if defined(DEBUG)
  Serial.print("id3data     ");
  Serial.println(info);
#endif
  char *indx;
  indx = strstr(info, "Artist: ");
  if (indx == info)
  {
    cpycharar(artist, info + 8, strlen(info) - 8);
    updateartist = true;
  }
  else
  {
    indx = strstr(info, "Title: ");
    if (indx == info)
    {
      cpycharar(title, info + 7, strlen(info) - 7);
      updatetitle = true;
    }
    else
    {
      indx = strstr(info, "Album: ");
      if (indx == info)
      {
        cpycharar(station, info + 7, strlen(info) - 7);
        updatealbum = true;
      }
    }
  }
}

#if defined(SDCARD)
void handleEOF()
{
  if (random_)
  {
    setTrack(-1);
  }
  else
  {
    if (getNextSDFileName())
    {
      SD_ix = SD_curindex;
      setTrack(SD_ix);
    }
  }
}

void audio_eof_mp3(const char *info)
{
  handleEOF();
}
#endif

// I decided to use exclusively a dedicated station name, defined in the playlist.
// The callback "audio_showstation" is used only in case of URL-test !!!
//--------------------------------------------------------------------------------

void audio_showstation(const char *info)
{
  if (testurlFlag)
  {
    char tmp[BUFFLEN];
    char *tmpbf = tmp;
    snprintf(tmp, BUFFLEN, info);
    cleanText(tmpbf);
    snprintf(station, BUFFLEN, tmpbf);
    show_station(tmpbf);
    updatemetadata = true;
    testurlFlag = false;
  }
}
void audio_showstreamtitle(const char *info)
{
  ESP_LOGW(TAG, " : \"%s\"", info);
  if (enc_menu_mode == VOLUME)
  {
    char *inx;
    uint8_t len;
    const char *p = info;
    uint16_t limit = BUFFLEN - 6;
    title[0] = '\0'; // preventive cleaning - otherwise if the separator is missing,
                     // the original content remains there
    char *_title = artist;
    inx = strstr(info, " - "); // Find separator between artist and title
    if (inx)                   // Separator found?
    {
      _title = title;
      len = (uint8_t)(inx - info);
      if (len < BUFFLEN) // no need to shorten the artist
      {
        cpycharar(artist, info, len);
        p = inx + 3; //+ strlen(" - ")
      }
      else // artist needs to be shortened
      {
        artist[0] = '\0';
        // it is very unlikely that the length of artist would exceed the buffer...
        // so nothing will happen, in that case we will display nothing
      }
    }
    // now the "title" part needs to be processed (it starts at position "p")
    // the integrity of the words is preserved when truncating
    if ((uint16_t)strlen(p) > (BUFFLEN - 1)) // title needs to be shortened
    {
      const char *q = p;
      const char *last = p;
      for (uint16_t i = 0; i <= limit; i++)
      {
        if (*q == ' ')
        {
          last = (char *)q;
        }
        q++;
      }
      if (last > p)
      {
        memcpy(_title, p, (int)(last - p));
        memcpy(_title + (int)(last - p), " ...", 5);
      }
      else
      {
        cpycharar(_title, p, BUFFLEN - 1);
      }
    }
    else // no need to shorten the title
    {
      strcpy(_title, p);
    }
    updatemetadata = true;
  }
}
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
void loop()
{
  /*
  if (rollbacktimer != 0)
  {
    if ((millis()-rollbacktimer) >= 60000)
    {
      esp_ota_mark_app_valid_cancel_rollback();
      ESP_LOGW(TAG, "Application state marked with the \"ESP_OTA_IMG_VALID\" !");
      rollbacktimer = 0;
    }
  }
  */
  char timetxt2[9];
  char shorttimetxt[6];
  char sub[3];
  uint32_t now_;
  uint8_t ix;
  if (gotIP)
  {
    WF_MODE = WF_STA;
    dispmode = DSP_OTHER;
    tft.fillScreen(TFT_BLACK);
    u8g2.setFont(u8g2_font_t0_17_me);
    uint8_t offset = 6 + u8g2.getFontDescent() + u8g2.getFontAscent();
    uint8_t linehgt = offset + 15;
    u8g2.setForegroundColor(TFT_WHITE);
    char charbuf[24];
    sprintf(charbuf, "RadioESP32 %s", STRINGIFY(VERSION));
    drawUTF8(0, offset, charbuf);
    drawUTF8(0, linehgt + offset, "SSID:");
    drawUTF8(0, 2 * linehgt + offset - 8, WiFi.SSID().c_str());
    drawUTF8(0, 3 * linehgt + offset, "IP Address:");
    IPAddress ip = WiFi.localIP();
    sprintf(charbuf, "%d.%d.%d.%d", ip[0], ip[1], ip[2], ip[3]);
    drawUTF8(0, 4 * linehgt + offset - 8, charbuf);
    if (reconnect)
    {
      vTaskDelay(8000 / portTICK_PERIOD_MS);
      if (pmode == PM_RADIO)
      {
        audpreset = 254;
      }
      reconnect = false;
    }
    else
    {
      vTaskDelay(4000 / portTICK_PERIOD_MS);
      reqpreset = enc_preset;
    }
    setMutepin(0, false);
    changeDispMode(DSP_RADIO);
    if (pmode == PM_RADIO)
    {
      char nr[6];
      sprintf(nr, "[%02d] ", presets[enc_preset].nr);
      cpycharar(station, nr, 5);
      cpycharar(station + 5, presets[enc_preset].name, BUFFLEN - 6);
      show_station(station);
    }
    gotIP = false;
  }
  if (APstart)
  {
    u8g2.setFont(u8g2_font_t0_17_me);
    u8g2.setBackgroundColor(TFT_BLACK);
    u8g2.setForegroundColor(TFT_WHITE);
    uint8_t offset = 6 + u8g2.getFontDescent() + u8g2.getFontAscent();
    uint8_t linehgt = offset + 15;
    char charbuf[24];
    sprintf(charbuf, "RadioESP32 - %s", STRINGIFY(VERSION));
    drawUTF8(0, offset, charbuf);
    u8g2.setBackgroundColor(TFT_WHITE);
    u8g2.setForegroundColor(TFT_BLACK);
    drawUTF8(0, linehgt + offset, "AP SSID:");
    drawUTF8(0, 2 * linehgt + offset - 8, WiFi.softAPSSID().c_str());
    drawUTF8(0, 3 * linehgt + offset, "AP IP Address:");
    IPAddress ip = WiFi.softAPIP();
    sprintf(charbuf, "%d.%d.%d.%d", ip[0], ip[1], ip[2], ip[3]);
    drawUTF8(0, 4 * linehgt + offset - 8, charbuf);
    u8g2.setBackgroundColor(TFT_BLACK);
    u8g2.setForegroundColor(TFT_WHITE);
    APstart = false;
  }
  if (clockReq)
  {
#if defined(AUTOSHUTDOWN)
    if (pwofftime > 0)
    {
      changeDispMode(DSP_PWOFF);
    }
    else
    {
#endif
      switch (config->tmode)
      {
      case 3:
        changeDispMode(DSP_CLOCK);
        break;
      case 2:
        changeDispMode(DSP_DIMMED);
        break;
      case 1:
        changeDispMode(DSP_OFFED);
        break;
      default:
        break;
      }
#if defined(AUTOSHUTDOWN)
    }
#endif
    clockReq = false;
  }

  chk_enc(); // Check rotary encoder functions
  if (updatemetadata)
  {
    if (enc_menu_mode == VOLUME)
    {
      show_title(title);
      show_artist(artist);
    }
#if defined(AUTOSHUTDOWN)
    if (dispmode != DSP_ASD)
    {
#endif
      changeDispMode(DSP_RADIO);
#if defined(AUTOSHUTDOWN)
    }
#endif
    if (pmode == PM_RADIO)
    {
      sendRadio();
    }
#if defined(SDCARD)
    else
    {
      sendSDplayer(3); // useful for .ogg tracks !!!
    }
#endif
    updatemetadata = false;
  }
  if (updatealbum)
  {
    if (enc_menu_mode == VOLUME)
    {
      show_station(station);
    }
#if defined(AUTOSHUTDOWN)
    if (dispmode != DSP_ASD)
    {
#endif
      changeDispMode(DSP_RADIO);
#if defined(AUTOSHUTDOWN)
    }
#endif
#if defined(SDCARD)
    sendSDplayer(0);
#endif
    updatealbum = false;
  }
  if (updateartist)
  {
    if (enc_menu_mode == VOLUME)
    {
      show_artist(artist);
    }
#if defined(AUTOSHUTDOWN)
    if (dispmode != DSP_ASD)
    {
#endif
      changeDispMode(DSP_RADIO);
#if defined(AUTOSHUTDOWN)
    }
#endif
#if defined(SDCARD)
    sendSDplayer(1);
#endif
    updateartist = false;
  }
  if (updatetitle)
  {
    if (enc_menu_mode == VOLUME)
    {
      show_title(title);
    }
#if defined(AUTOSHUTDOWN)
    if (dispmode != DSP_ASD)
    {
#endif
      changeDispMode(DSP_RADIO);
#if defined(AUTOSHUTDOWN)
    }
#endif
#if defined(SDCARD)
    sendSDplayer(2);
#endif
    updatetitle = false;
  }
  if (time_req)
  {
    gettime(); // update timetxt (mandatory for big clock !)
    if (WiFi.status() == WL_CONNECTED)
    {
      time_req = false;
      if ((dispmode == DSP_RADIO) || (dispmode == DSP_DIMMED))
      {
        u8g2.setFont(u8g2_font_t0_17_mn); // time font
#if defined(AUTOSHUTDOWN)
        if (pwofftime > 0)
        {
          time(&now);
          uint32_t pwofft = pwofftime - now;
          u8g2.setForegroundColor(TFT_RED);
          secondsToHMS(pwofft, timetxt2);
          drawStr(WID - 8 * 9, 21, timetxt2);
          u8g2.setForegroundColor(TFT_WHITE);
        }
        else
        {
#endif // auto
          if (config->sdclock && pmode == PM_SDCARD)
          {
            uint32_t remtime = audio.getAudioFileDuration() - audio.getAudioCurrentTime();
            u8g2.setForegroundColor(TFT_YELLOW);
            secondsToHMS(remtime, timetxt2);
            drawStr(WID - 8 * 9, 21, timetxt2);
            u8g2.setForegroundColor(TFT_WHITE);
          }
          else
          {
            u8g2.setForegroundColor(TFT_WHITE);
            drawStr(WID - 8 * 9, 21, timetxt);
          }
#if defined(AUTOSHUTDOWN)
        }
#endif // auto
      }
      else if (dispmode == DSP_CLOCK)
      {
        cpycharar(shorttimetxt, timetxt, 5);
        if ((strcmp(shorttimetxt, oldtimetxt) != 0) || (strcmp(datetxt, olddatetxt) != 0))
        {
          cpycharar(olddatetxt, datetxt, 15);
          cpycharar(oldtimetxt, shorttimetxt, 5);
          u8g2.setFont(u8g2_font_inb42_mn);
          u8g2.setForegroundColor(TFT_WHITE);
          cpycharar(sub, timetxt, 2);
          uint8_t cw = u8g2.getUTF8Width(sub);
          uint8_t colw = min(cw / 2, (WID - 2 * cw));
          drawStr((WID - colw) / 2 - cw, HGT - 1, sub);
          cpycharar(sub, timetxt + 3, 2);
          drawStr((WID + colw) / 2, HGT - 1, sub);
          if (config->calendar)
          {
            u8g2.setFont(u8g2_font_inr19_mn);
            drawStr(0, 24, datetxt);
            u8g2.setFont(font);
            cw = u8g2.getUTF8Width(config->wdays[Weekday]);
            u8g2.drawUTF8(0, 60, SPACES); // clear line
            u8g2.drawUTF8((WID - cw) / 2, 60, config->wdays[Weekday]);
          }
        }
      }
#if defined(AUTOSHUTDOWN)
      else if (dispmode == DSP_PWOFF)
      {
        if (pwofftime > 0)
        {
          time(&now);
          uint32_t pwofft = pwofftime - now;
          sprintf(timetxt2, "%02d:%02d", pwofft / 60, pwofft % 60); // format new remaining time
                                                                    // u8g2.drawStr(WID - 8 * 9, 21, timetxt2);
          u8g2.setForegroundColor(TFT_RED);
          u8g2.setFont(u8g2_font_inb42_mn);
          cpycharar(sub, timetxt2, 2);
          uint8_t cw = u8g2.getUTF8Width(sub);
          uint8_t colw = min(cw / 2, (WID - 2 * cw));
          drawStr((WID - colw) / 2 - cw, HGT - 1, sub);
          cpycharar(sub, timetxt2 + 3, 2);
          drawStr((WID + colw) / 2, HGT - 1, sub);
        }
      }
#endif
    }
  }
  if ((dispmode == DSP_RADIO) || (dispmode == DSP_DIMMED))
  {
    displayloop();
  }

  if (((config->tmode > 0) && (dispmode == DSP_CLOCK)) || (dispmode == DSP_PWOFF))
  {
    // colon blick
    now_ = millis();
    if (now_ - lastblick > 500)
    {
      lastblick = now_;
      coloncolor = !coloncolor;
      drawColon(coloncolor);
    }
  }
  if (sdp_icons_req)
  {
    sdp_icons();
    sdp_icons_req = false;
  }
  if (toggle_req)
  {
    jumptobtls();
    toggle_req = false;
  }
  if (proc1s_req)
  {
#if defined(SDCARD)
    if (pmode == PM_SDCARD)
    {
      if (audio.isRunning())
      {
        uint32_t pstn = audio.getAudioCurrentTime();
        if (pstn == pastpos)
        {
          if (poscounter++ == 8)
          {
            poscounter = 0;
            pastpos = 0xFFFFFFFF;
            handleEOF();
          }
        }
        else
        {
          pastpos = pstn;
          poscounter = 0;
          if (weso.count() > 0)
          {
            sendSDstat(pstn);
            prgrssbar(pstn, false);
          }
        }
      }
    }
#endif
    proc1s_req = false;
  }
  if (proc5s_req)
  {
    ESP_LOGW(TAG, "Free heap, free stack: %s, %d", String(ESP.getFreeHeap()), uxTaskGetStackHighWaterMark(NULL));
    if (weso.count() > 0)
    {
      sendHeartBeat();
    }
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

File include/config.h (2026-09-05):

struct Config {
	bool default_ = 1;
	uint8_t defvol = 50;
	int8_t bass = 0;
	int8_t mid = 0;
	int8_t treble = 0;
	uint8_t defstat = 0;
	uint8_t seekstep = 30;
    char hostnm[24] = "RadioESP32";
    char ntpServer[24] = "pool.ntp.org";
	int ntpInterval = 15;
    char timeZone[40] = "CET-1CEST,M3.5.0,M10.5.0/3";
    char tzname[24] = "Europe/Prague";
    char dateformat[11] = "dd-mm-yyyy";
	uint8_t backlight1 = 150;
	uint8_t backlight2 = 0;
	uint16_t refr = 100;
	uint8_t scrollgap = 5;
	uint16_t idle = 30;
	uint8_t tmode = 1;
#if defined(BATTERY)
	uint16_t bat0 = 4094;
	uint16_t bat100 = 4095;
	uint8_t lowbatt = 0;
	uint8_t critbatt = 10;
	uint16_t batw = 1000;
	bool batenabled = false;
#endif
	uint8_t sdclock = 1;
	uint8_t calendar = 0;
	uint8_t bclkpin = 255;
	uint8_t doutpin = 255;
	uint8_t wspin = 255;
	uint8_t dsptype = 128;
	uint8_t angle = 0;
	uint8_t bckpin = 255;
	uint8_t bckinv = 0;
	uint8_t extpullup = 0;
#if defined(SDCARD)
	uint8_t sdpullup = 0;
	uint8_t sddpin = 255;
#endif
	uint8_t encclkpin = 255;
	uint8_t encdtpin = 255;
	uint8_t encswpin = 255;
	uint8_t irpin = 255;
	uint8_t mutepin = 255;
#if defined(AUTOSHUTDOWN)
	uint8_t onoffipin = 255;
	uint8_t onoffopin = 255;
	uint8_t dasd = 20;
#endif
    uint8_t btauto = 1;
    uint8_t btaction = 1;
    uint16_t btcount = 32;
    IPAddress apaddress = {192, 168, 4, 1};
    IPAddress apsubnet = {255, 255, 255, 0};
    char apssid[33] = "RadioESP32";
    char btname[33] = "RadioESP32";
    char wdays[7][24] = {"Monday","Tuesday","Wednesday","Thursday","Friday","Saturday","Sunday"};
};

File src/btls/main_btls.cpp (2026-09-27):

#define MYSTR(A) #A
#define STRINGIFY(A) MYSTR(A)
#include "freertos/FreeRTOS.h"
#include "freertos/task.h"
#include "Arduino.h"
#include <ArduinoJson.h>
#define NO_LED_FEEDBACK_CODE        // saves 92 bytes program memory
#define EXCLUDE_UNIVERSAL_PROTOCOLS // Saves up to 1000 bytes program memory.
#define EXCLUDE_EXOTIC_PROTOCOLS    // saves around 650 bytes program memory if all other protocols are active
#include <IRremote.hpp>
#include "HW_Manager.h"
Config *config;

// Global variables
bool pauseflag = false;
int volume = 0;
bool toggle_req = false;
//uint32_t rollbacktimer = 0;

#include "display1.h"
#define A2DP_I2S_AUDIOTOOLS 0 // Suppress warning "AudioTools library is not included first or installed"
#include "BluetoothA2DPSink.h"
#undef A2DP_I2S_AUDIOTOOLS
#include "ESP_I2S.h"
#include "esp_log.h"
#include "esp_ota_ops.h"
#include "esp_system.h"
#include "nvs_flash.h"

#include <LittleFS.h>

#define FSIF false // Not format LittleFS if not existing !!!

const char *TAG = "MAIN";

#include "configManager.h"



I2SClass i2s;
BluetoothA2DPSink a2dp_sink(i2s);

char *convert_to_c_data_buffer(uint8_t const *ptr)
{
  return reinterpret_cast<char *>(const_cast<uint8_t *>(ptr));
}

void avrc_metadata_callback(uint8_t id, const uint8_t *text)
{
  if ((dispmode == DSP_OTHER) || (dispmode == DSP_LOWBATT))
  {
    return;
  }
  // 1. For sure: If the text does not exist or is empty, immediately jump out
  if (text == NULL || text[0] == '\0')
    return;

  if (id == ESP_AVRC_MD_ATTR_PLAYING_TIME)
  {
    // 2. Check: Live streams often send non-numeric texts.
    // We will check whether there is really a digit in the first place.
    if (text[0] >= '0' && text[0] <= '9')
    {
      AudioFileDuration = strtoul((const char *)text, nullptr, 10);
    }
    else
    {
      AudioFileDuration = 0; // For a live stream, we set the length to 0
    }
    return; // Done, we don't need to continue with the lyrics for the playing time
  }

  char *constu_ptr = convert_to_c_data_buffer(text);
  if (strlen(constu_ptr) > (BUFFLEN - 1))
  {
    ESP_LOGE(TAG, "Callback text too long: %i", strlen(constu_ptr));
    return;
  }

  if (id == ESP_AVRC_MD_ATTR_ALBUM)
  {
    cpycharar(station_input, constu_ptr, BUFFLEN - 1);
    updateLine(0, station_input);
  }
  else if (id == ESP_AVRC_MD_ATTR_TITLE)
  {
    cpycharar(title_input, constu_ptr, BUFFLEN - 1);
    updateLine(1, title_input);
  }
  else if (id == ESP_AVRC_MD_ATTR_ARTIST)
  {
    cpycharar(artist_input, constu_ptr, BUFFLEN - 1);
    updateLine(2, artist_input);
  }
}

void avrc_rn_play_pos_callback(uint32_t play_pos)
{
  if ((dispmode == DSP_OTHER) || (dispmode == DSP_LOWBATT))
  {
    return;
  }
  if (AudioFileDuration >= play_pos)
  {
    p_pos = play_pos;
  }

  prgrssbarflag = true;
}

// Connection state callback function
void connection_state_changed(esp_a2d_connection_state_t state, void *ptr)
{
  if (state == ESP_A2D_CONNECTION_STATE_CONNECTED)
  {
    volume = a2dp_sink.get_volume();
    dispVolume = volume;
    ESP_LOGW(TAG, "volume = %i", volume);
    iconflag0 = PI_BT_ON;
    btconnicon = PI_BT_ON;
    volbarflag = true;
  }
  else if (state == ESP_A2D_CONNECTION_STATE_DISCONNECTED)
  {
    iconflag0 = PI_BT_OFF;
    btconnicon = PI_BT_OFF;
    station_input[0] = '\0';
    updateLine(0, station_input);
    title_input[0] = '\0';
    updateLine(1, title_input);
    artist_input[0] = '\0';
    updateLine(2, artist_input);
  }
}

void avrc_rn_playstatus_callback(esp_avrc_playback_stat_t playback)
{
  switch (playback)
  {
  case esp_avrc_playback_stat_t::ESP_AVRC_PLAYBACK_STOPPED:
    iconflag2 = PI_STOP;
    statusicon = PI_STOP;
    break;
  case esp_avrc_playback_stat_t::ESP_AVRC_PLAYBACK_PLAYING:
    pauseflag = false;
    iconflag2 = PI_PLAY;
    statusicon = PI_PLAY;
    break;
  case esp_avrc_playback_stat_t::ESP_AVRC_PLAYBACK_PAUSED:
    pauseflag = true;
    iconflag2 = PI_PAUSE;
    statusicon = PI_PAUSE;
    break;
  default:
    ESP_LOGW(TAG, "Got unknown playback status %d\n", playback);
    break;
  }
}

void bootToPartition(esp_partition_subtype_t subtype, const char *name)
{
  ESP_LOGW(TAG, ">>> Finding the right partition: %s...\n", name);
  const esp_partition_t *target_part = esp_partition_find_first(ESP_PARTITION_TYPE_APP, subtype, NULL);

  if (target_part != NULL)
  {
    esp_err_t err = esp_ota_set_boot_partition(target_part);
    if (err == ESP_OK)
    {
      ESP_LOGW(TAG, "Bootloader set to %s. Preparing hardware reset...\n", name);

      // 1. Clean shutdown of a running wireless subsystem
      ESP_LOGW(TAG, "Deinitializing Bluetooth A2DP & I2S...");
      // .end(true) disconnects BT, turns off the radio and frees I2S DMA memory
      a2dp_sink.end(true);
      delay(150); // Short pause to safely complete I2S deinitialization

      // 2. NVS deinitialization (flash write and close)
      nvs_flash_deinit();
      delay(500);
      // DISABLE INTERRUPTS - FreeRTOS and all tasks freeze a second before death
      noInterrupts();

    // DIRECT HARDWARE RESET VIA CONTROLLER RTC REGISTERS
    // Address 0x3ff48000 is the base address of RTC_CNTL on ESP32
    // Writing the value will cause an immediate system reboot of the entire SoC at the silicon level
    *((volatile uint32_t *)(0x3ff48000 + 0x00)) = 0x9c000000; 
      // A processor trap from which there is no return
      while(1)
      {
        asm volatile("nop");
      }
    }
    else
    {
      ESP_LOGW(TAG, "ERROR writing to bootloader: %d\n", err);
    }
  }
  else
  {
    ESP_LOGE(TAG, "ERROR: Partition %s not found in memory!\n", name);
  }
}

void pausePlay()
{
  pauseflag = !pauseflag;
  if (pauseflag)
  {
    a2dp_sink.pause();
  }
  else
  {
    a2dp_sink.play();
  }
}

void mute()
{
  muteflag = !muteflag; // Mute/unmute REQUEST
  setMutepin(muteflag, false);
  iconflag1 = (muteflag + 7);
  ESP_LOGW(TAG, "Mute set to %d", muteflag);
  if (muteflag)
  {
    ESP_LOGW(TAG, "volume = %i", volume);
    a2dp_sink.set_volume(0);
    dispVolume = 0;
    volbarflag = true;
  }
  else
  {
    a2dp_sink.set_volume(volume);
    dispVolume = volume;
    volbarflag = true;
  }
}
void updateVolume(int step)
{
  int voloffset = 5 * step; // Step by 4 percent
  volume = volume + voloffset;

  if (volume < 0) // Limit volume
  {
    volume = 0; // Limit to normal values
  }
  else if (volume > 127)
  {
    volume = 127; // Limit to normal values
  }
  a2dp_sink.set_volume(volume);
  dispVolume = volume;
  volbarflag = true;
  ESP_LOGW(TAG, "volume = %i", volume);
  muteflag = false; // Mute off
  setMutepin(muteflag, false);
  iconflag1 = (muteflag + 7);
}
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
